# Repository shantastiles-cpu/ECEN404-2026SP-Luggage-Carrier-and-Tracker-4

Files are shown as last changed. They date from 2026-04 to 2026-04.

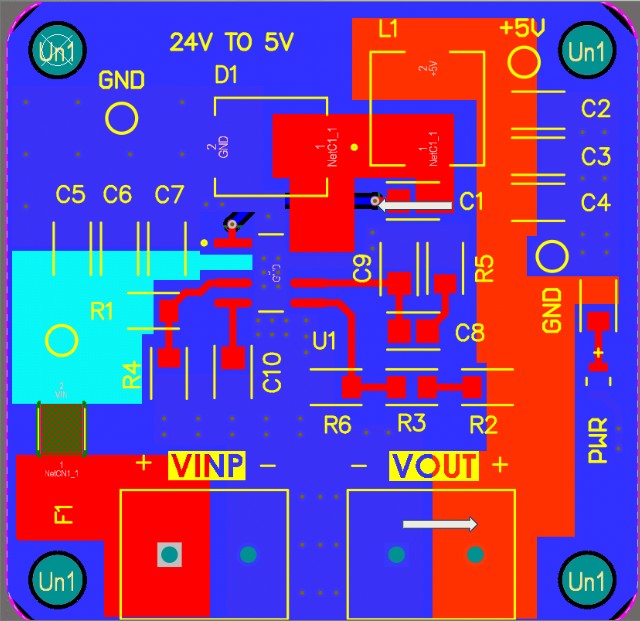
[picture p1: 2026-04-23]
Obstacle Avoidance Subsystem/Buck PCB layout.jpg

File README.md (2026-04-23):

# 🧳 Luggage Carrier and Tracker
ECEN 404 - Senior Design 2025 - 2026

A smart luggage-carrying rover that automatically follows its owner, avoids obstacles, and provides real-time tracking to relieve user fatigue and improve mobility.

## 📌 Project Overview
Problem Statement: Carrying luggage through large areas causes fatigue and logistical issues, particularly for the elderly or disabled.

Solution: An autonomous rover capable of following a designated user while navigating complex environments safely.

## 🛠 Subsystem Breakdown
This project is divided into four major technical subsystems. Detailed documentation and source code for each can be found in their respective directories:

App Subsystem: Flutter-based mobile application for user interface, luggage control, and Supabase integration.

Navigation Subsystem: Core logic for path planning and motor control.

Obstacle Avoidance Subsystem: Sensor integration (Ultrasonic) to ensure safe travel.

Tracking Subsystem: UWB or GPS-based logic for "follow-me" functionality.

## 💻 Tech Stack
Languages: Dart (Flutter) and Python

Cloud/Backend: Supabase (Database & Authentication)

Hardware: Raspberry PI

## 👥 The Team
@shantastiles-cpu

@pgarc04-maker

@aarifnaqvii

@Matt0032

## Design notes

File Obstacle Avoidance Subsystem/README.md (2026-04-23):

## Obstacle Avoidance and Weight Detection Subsystem

This subsystem covers the rover’s obstacle avoidance and weight detection functions.

It includes the ultrasonic sensing hardware and test code, the load cell scale and test code, and the final integrated navigation file where both systems are connected into the full rover operation.

🚀 Getting Started

To use this subsystem, review the included hardware and software files for ultrasonic sensing, load cell testing, and full-system integration.

### 1. Included Files

**four_sensors**
Code used to test the operation of the ultrasonic sensor array. These sensors are powered through a perf board and used to detect obstacles around the rover.

**read_weight**
Code used to test the operation of the load cell luggage scale and output weight readings in the terminal.

**NAVIAPP_MattUpdates4.py**
This is the main integration file where the obstacle avoidance and weight detection systems are combined into the rover’s full navigation and control system.

### 2. Hardware Notes

A large portion of this subsystem involved hardware design and integration.

This includes:

* Ultrasonic sensor array powered through a perf board
* Load cell and HX711 amplifier for luggage weight detection
* Buck converter PCB designed to step 24V down to 5V for Raspberry Pi power

A buck converter PCB was designed and tested for powering the Raspberry Pi from the rover battery system. The board was able to operate at 24V and supply 5A, but because the batteries could produce about 25V, the design was rated slightly too low and the PCB failed under that higher input. The design files and layout have still been included as part of this subsystem.

### 3. Integration

The ultrasonic sensing and weight detection systems are both integrated into the main rover navigation file:

**NAVIAPP_MattUpdates4.py**

This file is located in the home section of the repository and connects these safety systems with the rover’s navigation and control logic.

## Features

Obstacle detection using ultrasonic sensors

Perf board powered sensor array

Load cell luggage weight measurement

Terminal-based weight reading output

Integrated obstacle avoidance logic

Integrated luggage removal safety stop

Buck converter PCB design for Pi power

Combined operation in rover navigation code

Perf board power distribution
Buck converter PCB design

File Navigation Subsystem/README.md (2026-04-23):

# Navigation Subsystem

**Texas A&M University | Electrical & Computer Engineering**

This repository contains the core **Navigation Control Subsystem** for the Luggage Rover 37 capstone project. Operating on a Raspberry Pi 5, this subsystem acts as the brain of the rover's drivetrain. It is fundamentally built around an advanced, mass-adaptive PID controller that translates raw spatial coordinates into smooth, stable motor commands for a differential-drive skid-steer chassis.

## 🚀 System Overview

The Luggage Rover operates with a highly variable payload (0 to 20+ lbs). A statically tuned PID would either respond too sluggishly when fully loaded or violently oscillate when empty. 

To solve this, our navigation core implements **Real-Time Gain Scheduling**. By continuously polling an integrated HX711 load cell, the software dynamically scales the proportional, integral, and derivative coefficients on the fly, ensuring mathematically optimal damping and rise times regardless of the luggage mass.

## ✨ Core PID Architecture

* **Dual-Axis Independent Loops:** The system utilizes two asynchronous PID controllers:
  * **Distance PID:** Governs forward/reverse linear acceleration to maintain a strict 1.0m follow buffer.
  * **Heading PID:** Implements 360-degree wrap-around logic to calculate the shortest rotational path to align the chassis with the user's UWB tag.
* **Real-Time Gain Scheduling:** Actively interpolates `Kp`, `Ki`, and `Kd` parameters based on live payload data, providing necessary inertial load compensation for the heavy Sabertooth-driven drivetrain.
* **Kinematic Slop Compensation:** Injects immediate dynamic power offsets directly to the PID output to break the static friction of heavy rubber tires before the integral loop is forced to "spool up" and cause overshoot.
* **Zero-Effort Deadbands:** Custom 5.0 cm and 5.0° mathematical tolerances immediately cut motor output to absolute zero upon reaching the target zone, eliminating drivetrain micro-jitter and preventing integral windup while resting.
* **Integral Anti-Windup:** Strict mathematical clamping on the integral accumulator prevents runaway oscillation when tracking targets at extended, out-of-bounds ranges.

## 🛠️ Hardware Interface

* **Compute:** Raspberry Pi 5 (Running Python 3)
* **Motor Driver:** Sabertooth 25x2 Dual Motor Controller (Serial at 115200 baud)
* **Telemetry Input:** X/Y tracking coordinates provided by a secondary UWB localization script.

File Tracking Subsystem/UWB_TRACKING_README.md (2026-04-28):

# 📡 UWB Tracking Subsystem

> Real-time 2D user positioning for the Luggage Carrier Rover using Ultra-Wideband ranging, trilateration, and EMA filtering.

---

## Table of Contents

- [Overview](#overview)
- [Hardware](#hardware)
- [Coordinate System](#coordinate-system)
- [Firmware](#firmware)
  - [Anchor Firmware](#anchor-firmware)
  - [Tag Firmware](#tag-firmware)
  - [Antenna Delay Calibration](#antenna-delay-calibration)
- [Software Pipeline](#software-pipeline)
  - [Stage 1 — Port Detection](#stage-1--port-detection)
  - [Stage 2 — Serial Ingestion](#stage-2--serial-ingestion)
  - [Stage 3 — Range Filtering](#stage-3--range-filtering)
  - [Stage 4 — Position Solving](#stage-4--position-solving)
  - [Stage 5 — EMA Smoothing](#stage-5--ema-smoothing)
  - [Stage 6 — Angle and Distance Computation](#stage-6--angle-and-distance-computation)
  - [Stage 7 — Control Distance Rejection](#stage-7--control-distance-rejection)
  - [Stage 8 — Quality Gating](#stage-8--quality-gating)
  - [Stage 9 — Confidence Scoring](#stage-9--confidence-scoring)
- [Configuration](#configuration)
- [Pose Output](#pose-output)
- [Known Limitations](#known-limitations)
- [Dependencies](#dependencies)
- [File Structure](#file-structure)

---

## Overview

The UWB tracking subsystem provides real-time 2D position of a user-carried tag relative to two anchors mounted on the rover. Each anchor independently measures its distance to the tag and reports the result to the Raspberry Pi 5 over USB serial. The Pi solves the tag's position using trilateration and passes distance, heading angle, and confidence to the navigation controller.

---

## Hardware

| Component | Details |
|---|---|
| Anchors | 2× Makerfabs ESP32 UWB (DW1000), USB → Raspberry Pi 5 |
| Tag | 1× Makerfabs ESP32 UWB (DW1000), carried by user |
| Host | Raspberry Pi 5 running `NAVIAPP_MattsUpdates4.py` |
| Anchor separation | 0.65 m (±0.325 m from rover centreline) |
| Ranging mode | `MODE_LONGDATA_RANGE_LOWPOWER` |
| Serial baud rate | 115200 |

---

## Coordinate System

```
             Tag (x, y)
                •
                |
         y      |       ← Y = depth in front of rover
         ↑      |
         |      |
A1 ──────┼──────────── A2      ← anchor wall  (Y = 0)
    (-0.325, 0)  →x  (0.325, 0)
              origin (0, 0)
```

| Axis | Description |
|---|---|
| **X** | Lateral offset from anchor midpoint. Negative = left, positive = right |
| **Y** | Depth in front of the anchor wall. Always positive in normal operation |
| **Distance** | Straight-line distance from rover reference point `(REF_OFFSET_X, REF_OFFSET_Y)` to tag |
| **Angle** | Heading from rover reference point to tag, measured from forward axis. Negative = left, positive = right |

---

## Firmware

### Anchor Firmware

> Files: `anchor1/anchor1.ino`, `anchor2/anchor2.ino`

Each anchor has a unique EUI-64 address and performs DS-TWR (Double-Sided Two-Way Ranging) with the tag. On each completed ranging exchange it streams a JSON frame over USB serial:

```json
{"anchor":"0100","range":1.2340,"dbm":-82.1}
```

On boot it emits an identification message used for auto-detection:

```json
{"event":"boot","anchor":"1"}
```

### Tag Firmware

> File: `tag/tag.ino`

The tag uses the library default antenna delay of `16384` and participates passively in DS-TWR ranging. It does **not** compute positions or transmit data to the Pi — all computation happens on the Pi side.

### Antenna Delay Calibration

The `ANTENNA_DELAY` constant in each anchor compensates for the board's physical hardware propagation delay. To calibrate:

1. Place the tag exactly **1.000 m** from the anchor with clear line of sight
2. Note the reported distance (`measured_m`)
3. Apply the correction formula:

```
new_delay = current_delay + round((measured_m − 1.000) / 0.0046)
```

4. Update `ANTENNA_DELAY` in the anchor firmware and reflash
5. Repeat until the reading is within a few centimetres of 1.000 m

> **Note:** The tag always uses `16384`. Only the anchors are calibrated.  
> **Important:** Calibrate with both anchors mounted on the rover and active simultaneously — the ranging environment affects the result.

Alternatively, flash `anchor_calibrate/anchor_calibrate.ino` which runs a binary search to converge on the correct delay automatically and prints the final value to Serial Monitor.

---

## Software Pipeline

All tracking logic lives in `LocalUwbTracker` inside `NAVIAPP_MattsUpdates4.py`.

```
USB Serial                     Pi Host
───────────────────────────────────────────────────────────────
Anchor 1 ──► AnchorReader 1 ──► bounds check
                                 height compensation           Stage 3
                                 median filter (window=3)
                                        │
Anchor 2 ──► AnchorReader 2 ──►        ▼
             (same filters)    solve_position()                Stage 4
                                 law of cosines → (x, y)
                                        │
                                        ▼
                                 EMA smoothing                 Stage 5
                                 alpha = 0.25
                                        │
                                        ▼
                               angle_deg, distance_m           Stage 6
                               from reference point
                                        │
                                        ▼
                               control drop rejection          Stage 7
                                        │
                                        ▼
                               is_pose_good() gate             Stage 8
                                        │
                                        ▼
                               confidence score                Stage 9
                                        │
                                        ▼
                               → Navigation Controller
```

---

### Stage 1 — Port Detection

At startup, `detect_anchor_ports()` probes USB ports **sequentially** with a 0.5 s gap between each. This avoids a DTR reset race condition where both ESP32s boot simultaneously and interfere with each other's UWB ranging. Each port is toggled via DTR to trigger an ESP32 reset and the boot message is read to confirm anchor presence.

---

### Stage 2 — Serial Ingestion

Two `AnchorReader` threads run in parallel, one per USB port. Each thread reads JSON frames continuously at 115200 baud. The anchor is marked `connected = True` on each valid reading and `connected = False` if no data is received for 3 seconds.

---

### Stage 3 — Range Filtering

Each raw range reading passes three operations in `AnchorReader._parse()`:

#### Bounds Check
```python
if rng < 0.05 or rng > 20.0:
    discard
```

#### Height Compensation

The DW1000 measures 3D slant range. If anchors and tag are at different heights, this is projected to the horizontal floor plane:

$$d_{horizontal} = \sqrt{range^2 - height\_diff^2}$$

where `height_diff = |ANCHOR_HEIGHT_M − TAG_HEIGHT_M|`.

If the slant range is shorter than the height difference (physically impossible noise floor), the reading is clamped to `0.01 m` rather than discarded.

#### Median Filter

A rolling window median filter (`window = 3`) suppresses impulsive multipath noise. Waits for at least 2 samples before outputting.

---

### Stage 4 — Position Solving

The two filtered distances `d1` (A1 → tag) and `d2` (A2 → tag), plus anchor separation `c`, form a triangle. The tag's 2D position is solved using the **law of cosines**:

$$\cos\alpha = \frac{d_1^2 + c^2 - d_2^2}{2 \cdot d_1 \cdot c}$$

$$\sin\alpha = \sqrt{1 - \cos^2\alpha}$$

$$x = d_1 \cdot \cos\alpha - \frac{c}{2}, \quad y = d_1 \cdot \sin\alpha$$

The `c/2` term shifts the origin from A1 to the anchor midpoint. `cos α` is clamped to `[−1, 1]` to absorb small ranging inconsistencies.

---

### Stage 5 — EMA Smoothing

An Exponential Moving Average (`EMA_ALPHA = 0.25`) is applied to raw `x` and `y` before computing angle and distance:

```python
ema_x = 0.25 * raw_x + 0.75 * ema_x
ema_y = 0.25 * raw_y + 0.75 * ema_y
```

Each update blends 25% new reading with 75% history, dampening high-frequency jitter from ranging inconsistencies.

| `EMA_ALPHA` | Behaviour |
|---|---|
| `0.1` | Very smooth, ~700 ms lag |
| `0.25` | Balanced — current setting, ~300–400 ms lag |
| `0.5` | Responsive, some residual jitter |
| `0.8` | Nearly raw output |

---

### Stage 6 — Angle and Distance Computation

From EMA-smoothed `x` and `y`, outputs are computed relative to the **rover reference point** `(REF_OFFSET_X, REF_OFFSET_Y)`:

```python
angle_deg          = atan2(x − REF_OFFSET_X,  y − REF_OFFSET_Y)
distance_control_m = hypot(x − REF_OFFSET_X,  y − REF_OFFSET_Y)
distance_display_m = hypot(x, y)
```

Using the reference point offset ensures `angle = 0°` aligns with the physical forward direction of the rover chassis rather than the anchor wall midpoint.

---

### Stage 7 — Control Distance Rejection

A secondary gate rejects implausible sudden distance drops that could cause an uncontrolled forward charge:

```python
if distance_control_m < MIN_VALID_CONTROL_M:       # 0.50 m
    if last_good − current > MAX_CONTROL_DROP_M:   # 0.35 m
        reject frame, hold last known good value
```

---

### Stage 8 — Quality Gating

Before the pose is passed to the follow controller, all four conditions must pass:

| Condition | Threshold |
|---|---|
| Reading age | < `stale_s` = 1.5 s |
| Anchor 1 connected | `True` |
| Anchor 2 connected | `True` |
| Confidence score | ≥ `min_conf` = 30% |

If any condition fails the rover holds position or transitions to `LOST_UWB` state.

---

### Stage 9 — Confidence Scoring

A 0–100 confidence score is computed from two components:

```
confidence = imbalance_score × 0.6 + distance_score × 0.4
```

- **Imbalance score** — penalises large differences between `d1` and `d2` (tag far off-centre)
- **Distance score** — penalises large Y values (ranging noise has greater angular effect at distance)

---

## Configuration

All tuning constants are defined near the top of `NAVIAPP_MattsUpdates4.py`:

| Constant | Default | Description |
|---|---|---|
| `ANCHOR_HEIGHT_M` | `0.29` | Anchor height above floor (m) |
| `TAG_HEIGHT_M` | `0.89` | Tag height above floor (m) |
| `REF_OFFSET_X` | `0.0` | Reference point X offset from anchor midpoint (m) |
| `REF_OFFSET_Y` | `0.15` | Reference point Y offset — distance in front of anchor wall (m) |
| `MIN_VALID_CONTROL_M` | `0.50` | Minimum believable control distance (m) |
| `MAX_CONTROL_DROP_M` | `0.35` | Maximum believable single-frame distance drop (m) |
| `EMA_ALPHA` | `0.25` | EMA smoothing factor |
| `median_window` | `3` | Median filter window size per anchor |
| `stale_s` | `1.5` | Maximum reading age before pose is stale (s) |
| `min_conf` | `30.0` | Minimum confidence score to act on pose (%) |

---

## Pose Output

`LocalUwbTracker.get()` returns:

```python
{
    "distance_cm":         float,   # control distance from rover reference point (cm)
    "distance_display_cm": float,   # display distance from anchor midpoint (cm)
    "angle_deg":           float,   # heading — negative = left, positive = right
    "confidence":          float,   # quality score 0–100
    "age_s":               float,   # seconds since last valid update
    "a1_connected":        bool,    # anchor 1 connection status
    "a2_connected":        bool,    # anchor 2 connection status
    "a1_age_s":            float,   # seconds since anchor 1 last reading
    "a2_age_s":            float,   # seconds since anchor 2 last reading
    "last_error":          str | None,
}
```

---

## Known Limitations

| Limitation | Detail |
|---|---|
| **Front/behind ambiguity** | With two anchors, `sin α ≥ 0` always — the system cannot distinguish front from behind. Assumes tag is always in front. A BNO055 compass would resolve this. |
| **Near-wall instability** | When tag is very close to anchor wall, small ranging errors produce large angular swings. Avoid operating below ~0.5 m depth. |
| **Multipath reflections** | Median window of 3 suppresses most spikes. Increasing to 5–7 improves rejection at the cost of additional lag. |
| **Antenna delay drift** | Effective delay shifts with temperature and two-anchor operation. Calibrate with both anchors mounted and active on the rover. |

---

## Dependencies

**Python (Pi host):**
```bash
pip3 install pyserial supabase
```

**Arduino (firmware):**
- `DW1000` by Thomas Trojer — install via Arduino Library Manager

---

## File Structure

```
anchor1/
└── anchor1.ino              # Anchor 1 firmware  (EUI-64: 01:00:5B:D5:A9:9A:E2:9C)
anchor2/
└── anchor2.ino              # Anchor 2 firmware  (EUI-64: 02:00:5B:D5:A9:9A:E2:9C)
tag/
└── tag.ino                  # Tag firmware       (antenna delay: 16384)
anchor_calibrate/
└── anchor_calibrate.ino     # Binary search antenna delay calibration sketch
NAVIAPP_MattsUpdates4.py     # Main application — contains LocalUwbTracker
```

---

*Tracking subsystem — Luggage Carrier and Tracker 4 | Team 37 | Texas A&M ECEN 404*

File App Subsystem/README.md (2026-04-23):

# Rover Navigation App

A Flutter-based rover companion app for live navigation, pairing, telemetry monitoring, and validation testing. This app connects to rover data streams, displays positioning and health information, supports manual and autonomous interaction workflows, and exports validation logs for latency and navigation analysis.

## 🚀 Getting Started
To run this app locally, follow these steps:

### 1. Prerequisites
Install the Flutter SDK.

Install Android Studio or VS Code with the Flutter extension.

Ensure you have a physical device or emulator ready.

Create Supabase account to prepare SQL schema

### 2. Installation
Clone the repository:

Bash
git clone https://github.com/shantastiles-cpu/ECEN404-2026SP-Luggage-Carrier-and-Tracker-4.git
Navigate to the App Subsystem directory:

Bash
cd "App Subsystem"
Get the required packages:

Bash
flutter pub get

### 3. Running the App
Launch the app on your connected device using:

Bash
flutter run

### 4. Prepping Database

Copy database_schema.sql commands to the table editor in Supabase

Note: Be sure to enable realtime updates for the tables

## Features

- Rover pairing and reconnection workflow
- Live UWB navigation display
- GPS/map view for rover and user positioning
- Rover telemetry and system health monitoring
- Manual and autonomous mode support
- Realtime Supabase data updates
- Validation testing tools for:
  - UWB and navigation pipeline latency
  - App event logging
  - CSV export for offline analysis
- Visual UI cards for rover state, pairing, and diagnostics

## Tech Stack

- **Flutter**
- **Dart**
- **Supabase**
- **Realtime data subscriptions**
- **CSV export for validation logs**

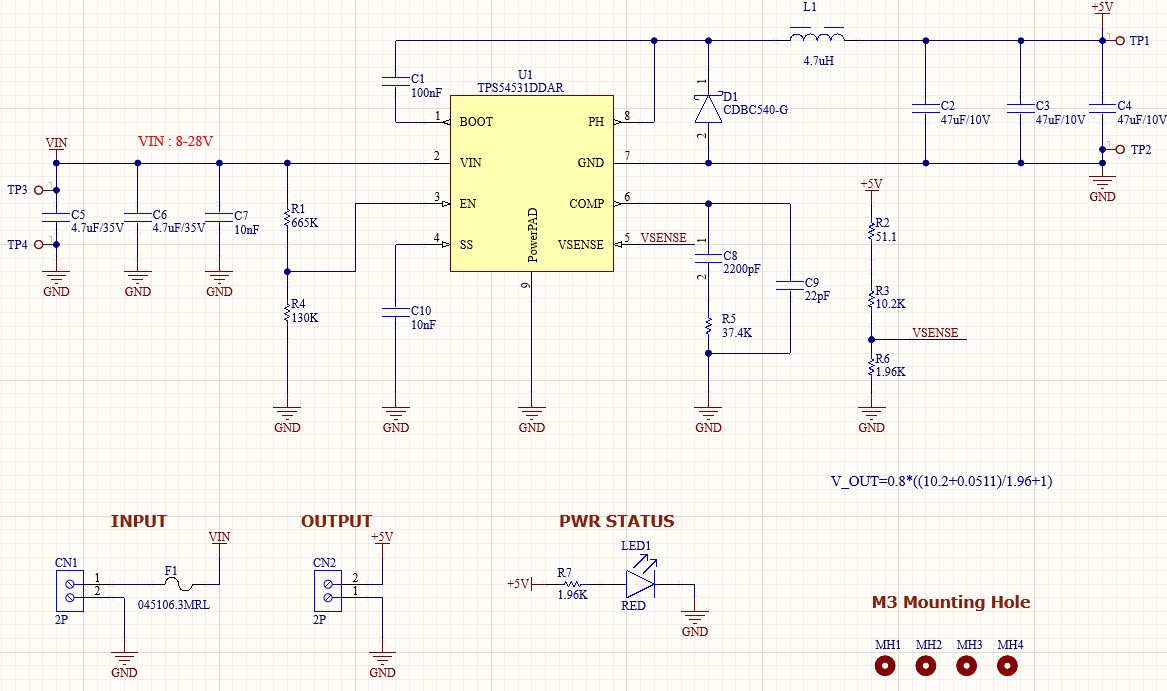
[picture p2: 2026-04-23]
Obstacle Avoidance Subsystem/Buck PCB schematic.jpg

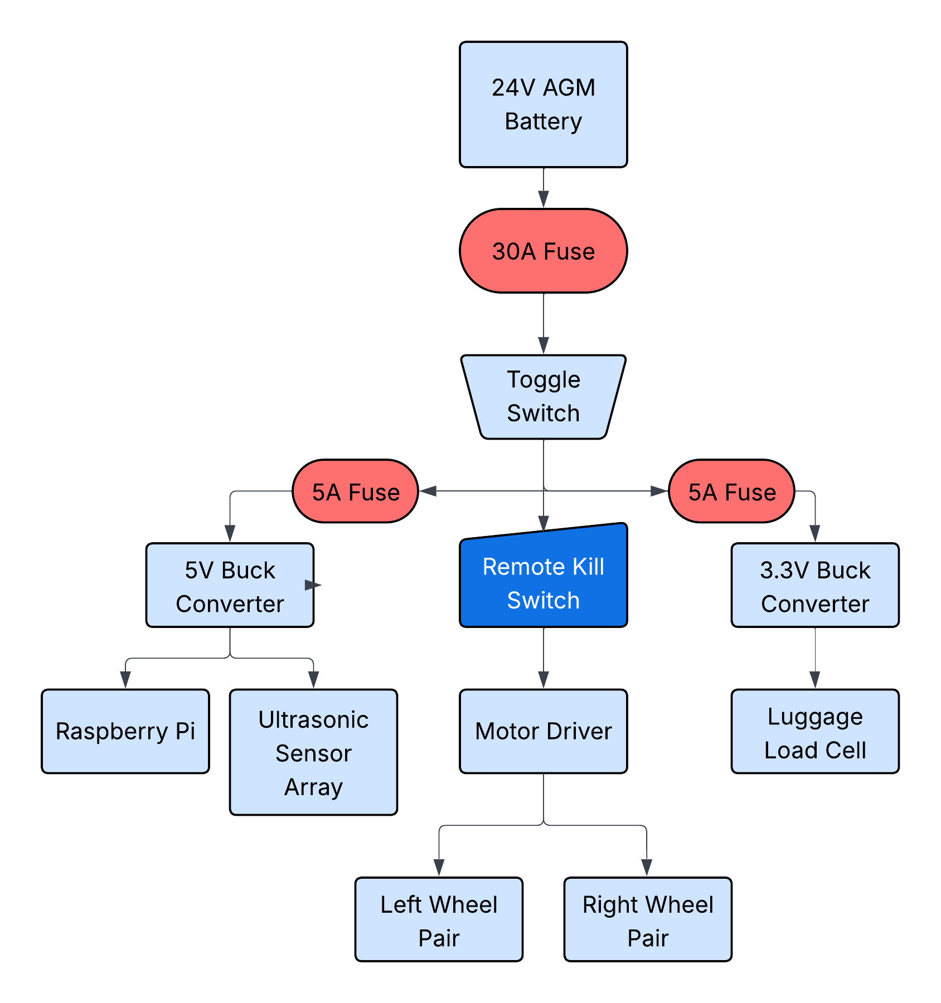
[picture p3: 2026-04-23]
Navigation Subsystem/Power Diagram.png

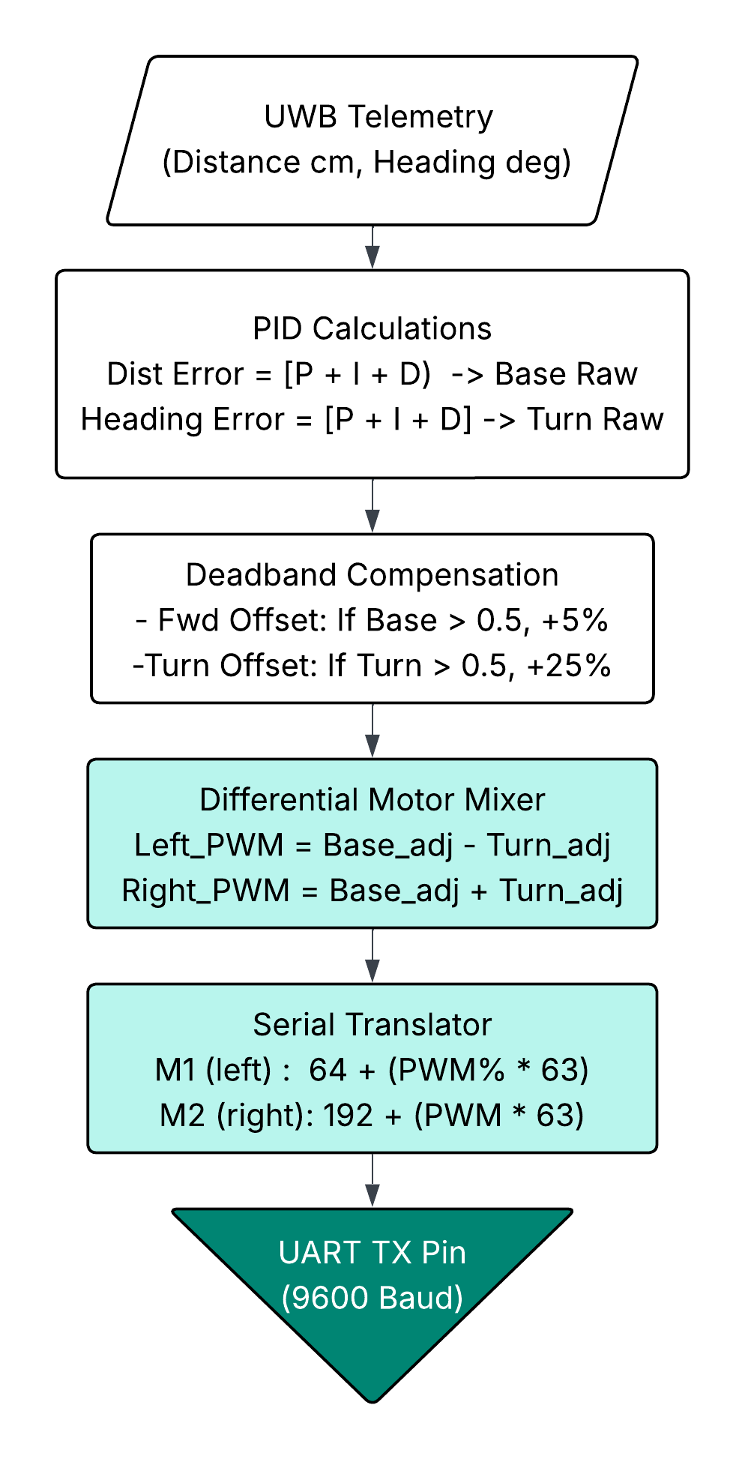
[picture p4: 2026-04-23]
Navigation Subsystem/PID diagram.png

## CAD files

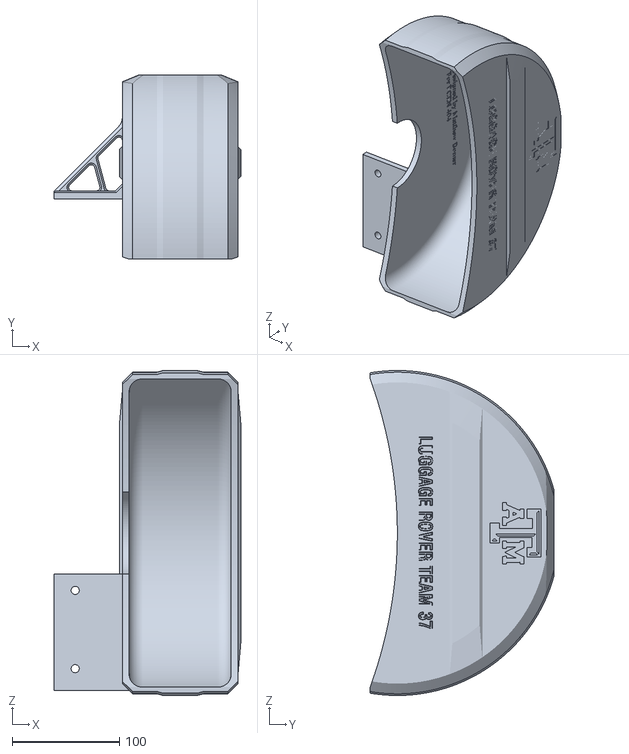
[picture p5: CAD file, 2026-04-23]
Navigation Subsystem/Wheel Arch.stl
174.0 x 171.5 x 303.2

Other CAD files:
Navigation Subsystem/Wheel Arch Mirrored.stl
Navigation Subsystem/Buck Converter Holder.ipt
Navigation Subsystem/Luggage Mount.ipt
Navigation Subsystem/Wheel Arch Mirrored.ipt
Navigation Subsystem/Wheel Arch.ipt

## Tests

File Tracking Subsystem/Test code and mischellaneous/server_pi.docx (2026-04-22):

import json

import numpy as np

import time

import paho.mqtt.client as mqtt

import csv

from datetime import datetime

import os

from collections import deque

# --- CONFIGURATION ---

MQTT_BROKER_IP = "localhost"

MQTT_BROKER_PORT = 1883

DATA_TOPIC = "uwb/tag/data"

STATUS_TOPIC = "uwb/tag/status"

RESULT_TOPIC = "uwb/tag/result"

# --- File Path ---

LOG_FILE_NAME = 'position_log.csv'

# --- 1. CALIBRATION ---

ANCHOR_BIAS = {

"1782": 0.0,

"1783": 0.0,

"1781": 0.0

}

# --- 2. GEOMETRY CONFIG ---

ANCHOR_CONFIG = {

"1782": [-0.204, 0.0],

"1783": [0.204, 0.0],

"1781": [0.0, 0.59]

}

# --- 3. PHYSICS LIMITS ---

MIN_DIST = 0.01

MAX_DIST = 50.0

TAG_HEIGHT = 0.7

MAX_SPEED_MPS = 3.0

ROOM_BOUNDS = { "x_min": -5.0, "x_max": 5.0, "y_min": -5.0, "y_max": 5.0 }

# --- 4. KNOWN START POSITION ---

# We use this to initialize the filter

TRUE_X = 0.0

TRUE_Y = 1.5

# --- 5. SMOOTHING SETTINGS ---

HISTORY_LENGTH = 10

# --- MINI KALMAN FILTER CLASS ---

class MiniKalmanFilter:

def __init__(self):

# --- CALIBRATION CHANGE: Initialize at Known Start ---

# State: [x, y, vx, vy]

# We start at the known position with 0 velocity

self.x = np.array([TRUE_X, TRUE_Y, 0.0, 0.0])

# Initial Uncertainty (P)

# We are very confident about position (low variance),

# but uncertain about velocity (high variance).

self.P = np.diag([0.1, 0.1, 5.0, 5.0])

self.Q = np.eye(4) * 0.0001

self.R = np.eye(2) * (0.3**2)

self.H = np.array([[1, 0, 0, 0], [0, 1, 0, 0]])

self.dt = 0.1

def predict(self):

F = np.array([[1, 0, self.dt, 0], [0, 1, 0, self.dt], [0, 0, 1, 0], [0, 0, 0, 1]])

self.x = np.dot(F, self.x)

self.P = np.dot(np.dot(F, self.P), F.T) + self.Q

def update(self, z):

z = np.array(z)

y = z - np.dot(self.H, self.x)

S = np.dot(np.dot(self.H, self.P), self.H.T) + self.R

K = np.dot(np.dot(self.P, self.H.T), np.linalg.inv(S))

self.x = self.x + np.dot(K, y)

self.P = np.dot((np.eye(4) - np.dot(K, self.H)), self.P)

def trilaterate_2d(anchors, distances):

anchors = np.array(anchors); distances = np.array(distances)

try:

p1 = anchors[0]; r1 = distances[0]

A, b = [], []

for i in range(1, len(anchors)):

pi = anchors[i]; ri = distances[i]

A.append(2 * (pi - p1))

b.append(r1**2 - ri**2 - np.dot(p1, p1) + np.dot(pi, pi))

pos, *_ = np.linalg.lstsq(np.array(A), np.array(b), rcond=None)

return np.array([pos[0], pos[1]])

except: return None

def on_connect(client, userdata, flags, rc):

print(f"Connected to MQTT Broker (Code: {rc})")

client.subscribe(DATA_TOPIC, qos=1)

client.subscribe(STATUS_TOPIC, qos=1)

def is_physically_possible(new_pos, last_pos, dt):

x, y = new_pos

if not (ROOM_BOUNDS["x_min"] <= x <= ROOM_BOUNDS["x_max"]):

print(f" ⚠️ REJECT: Out of bounds ({x:.2f}, {y:.2f})")

return False

if not (ROOM_BOUNDS["y_min"] <= y <= ROOM_BOUNDS["y_max"]):

print(f" ⚠️ REJECT: Out of bounds ({x:.2f}, {y:.2f})")

return False

distance_moved = np.linalg.norm(new_pos - last_pos)

speed = distance_moved / dt

if speed > MAX_SPEED_MPS:

print(f" ⚠️ REJECT: Speed violation ({speed:.2f} m/s)")

return False

return True

def on_message(client, userdata, msg):

if msg.topic == STATUS_TOPIC:

try:

status = msg.payload.decode('utf-8')

print(f"\n== STATUS UPDATE: Tag is now {status} ==\n")

except: pass

return

try:

payload_str = msg.payload.decode('UTF-8')

uwb_data = json.loads(payload_str)

uwb_list = uwb_data.get("links", [])

log_file_handle = client.log_file_handle

log_csv_writer = client.log_csv_writer

kf = client.kalman_filter

history = client.pos_history

current_time = time.time()

last_time = getattr(client, 'last_update_time', current_time - 0.5)

client.last_update_time = current_time

dt = current_time - last_time

kf.dt = dt if dt > 0 else 0.1

except Exception: return

current_anchors, current_distances = [], []

for link in uwb_list:

try:

addr = link.get("A"); raw_dist = float(link.get("R"))

if addr in ANCHOR_CONFIG:

bias = ANCHOR_BIAS.get(addr, 0.0)

d_raw = raw_dist - bias

if d_raw > TAG_HEIGHT:

d_horizontal = np.sqrt(d_raw**2 - TAG_HEIGHT**2)

if MIN_DIST < d_horizontal < MAX_DIST:

current_anchors.append(ANCHOR_CONFIG[addr])

current_distances.append(d_horizontal)

else:

current_anchors.append(ANCHOR_CONFIG[addr])

current_distances.append(0.01)

except Exception: pass

kf.predict()

is_good_measurement = False

tag_est = None

if len(current_anchors) >= 3:

candidate_pos = trilaterate_2d(current_anchors, current_distances)

if candidate_pos is not None:

last_x, last_y = float(kf.x[0]), float(kf.x[1])

if is_physically_possible(candidate_pos, np.array([last_x, last_y]), dt):

is_good_measurement = True

tag_est = candidate_pos

kf.update(z=tag_est)

else:

pass

x_filt_raw = float(kf.x[0])

y_filt_raw = float(kf.x[1])

history.append((x_filt_raw, y_filt_raw))

final_x = sum(p[0] for p in history) / len(history)

final_y = sum(p[1] for p in history) / len(history)

angle_rad = np.arctan2(final_x, final_y)

angle_deg = np.degrees(angle_rad)

dist_origin = np.sqrt(final_x**2 + final_y**2)

error_m = np.sqrt((final_x - TRUE_X)**2 + (final_y - TRUE_Y)**2)

print(f" Pos: ({final_x:.2f}, {final_y:.2f}) | Angle: {angle_deg:.1f}° | Error: {error_m:.2f}m")

try:

result_payload = json.dumps({

"x": final_x, "y": final_y, "angle": angle_deg, "dist": dist_origin, "error": error_m

})

client.publish(RESULT_TOPIC, result_payload)

except: pass

try:

timestamp = datetime.now().isoformat()

calc_x, calc_y = (tag_est[0], tag_est[1]) if is_good_measurement else (np.nan, np.nan)

log_data = [timestamp, calc_x, calc_y, final_x, final_y, angle_deg, dist_origin, TRUE_X, TRUE_Y, error_m]

log_csv_writer.writerow(log_data)

log_file_handle.flush()

except Exception: pass

def main():

print("\n>>> RUNNING SERVER v14 (Calibrated Start) <<<\n")

print(f"Filter Initialized at: ({TRUE_X}, {TRUE_Y})")

file_needs_header = not os.path.exists(LOG_FILE_NAME)

try:

log_file = open(LOG_FILE_NAME, 'a', newline='')

csv_writer = csv.writer(log_file)

if file_needs_header:

csv_writer.writerow(["timestamp", "x_calc", "y_calc", "x_filtered", "y_filtered", "angle_deg", "dist_origin", "x_true", "y_true", "error_m"])

log_file.flush()

except Exception as e: print(f"FATAL: {e}"); return

client = mqtt.Client()

client.kalman_filter = MiniKalmanFilter()

client.pos_history = deque(maxlen=HISTORY_LENGTH)

client.log_file_handle = log_file

client.log_csv_writer = csv_writer

client.last_update_time = time.time()

client.on_connect = on_connect

client.on_message = on_message

try: client.connect(MQTT_BROKER_IP, MQTT_BROKER_PORT, 60)

except Exception as e: print(f"Connection Error: {e}"); log_file.close(); return

client.loop_start()

print("Network loop started. Waiting for UWB data...")

try:

while True: time.sleep(1)

except KeyboardInterrupt:

client.loop_stop(); client.disconnect(); log_file.close()

print("Server stopped.")

if __name__ == '__main__':

main()

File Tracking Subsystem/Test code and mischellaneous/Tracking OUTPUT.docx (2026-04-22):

19:53:29 [INFO] Waiting for readings from both anchors…

19:53:29 [INFO] Waiting for readings from both anchors…

A1= 3.305 m A2= 3.240 m → X= +0.425 m Y= +3.235 m θ= +7.49°

19:53:31 [INFO] HTTP Request: POST https://jbhjvtfeezmityewhtwa.supabase.co/rest/v1/uwb_positions?on_conflict=robot_id "HTTP/2 200 OK"

A1= 3.330 m A2= 3.260 m → X= +0.461 m Y= +3.253 m θ= +8.07°

19:53:31 [INFO] HTTP Request: POST https://jbhjvtfeezmityewhtwa.supabase.co/rest/v1/uwb_positions?on_conflict=robot_id "HTTP/2 200 OK"

A1= 3.340 m A2= 3.270 m → X= +0.463 m Y= +3.263 m θ= +8.07°

19:53:31 [INFO] HTTP Request: POST https://jbhjvtfeezmityewhtwa.supabase.co/rest/v1/uwb_positions?on_conflict=robot_id "HTTP/2 200 OK"

A1= 3.340 m A2= 3.280 m → X= +0.397 m Y= +3.277 m θ= +6.91°

19:53:32 [INFO] HTTP Request: POST https://jbhjvtfeezmityewhtwa.supabase.co/rest/v1/uwb_positions?on_conflict=robot_id "HTTP/2 200 OK"

A1= 3.340 m A2= 3.270 m → X= +0.463 m Y= +3.263 m θ= +8.07°

19:53:32 [INFO] HTTP Request: POST https://jbhjvtfeezmityewhtwa.supabase.co/rest/v1/uwb_positions?on_conflict=robot_id "HTTP/2 200 OK"

A1= 3.300 m A2= 3.280 m → X= +0.132 m Y= +3.278 m θ= +2.30°

19:53:32 [INFO] HTTP Request: POST https://jbhjvtfeezmityewhtwa.supabase.co/rest/v1/uwb_positions?on_conflict=robot_id "HTTP/2 200 OK"

cd /home/matt/Desktop/Tracking

source .venv/bin/activate

python3 SUPA_uwb_host.py

18:54:08 [INFO] Detecting anchors — please wait…

18:54:08 [INFO] Scanning ports: ['/dev/ttyUSB0', '/dev/ttyUSB1']

18:54:10 [INFO] /dev/ttyUSB0 → anchor 2

18:54:10 [INFO] /dev/ttyUSB1 → anchor 1

18:54:14 [INFO] Anchor 1 → /dev/ttyUSB0 pos=(-0.25, 0.00) m

18:54:14 [INFO] Anchor 2 → /dev/ttyUSB1 pos=(0.25, 0.00) m

18:54:14 [INFO] [Anchor 1] Reading from /dev/ttyUSB0

18:54:14 [INFO] [Anchor 2] Reading from /dev/ttyUSB1

18:54:14 [INFO] Positioning started — Ctrl+C to stop

18:54:14 [INFO] Waiting for readings from both anchors…

18:54:14 [INFO] Waiting for readings from both anchors…

18:54:14 [INFO] Waiting for readings from both anchors…

18:54:14 [INFO] Waiting for readings from both anchors…

18:54:15 [INFO] Waiting for readings from both anchors…

18:54:20 [INFO] Waiting for readings from both anchors…

18:54:20 [INFO] Waiting for readings from both anchors…

18:54:20 [INFO] Waiting for readings from both anchors…

18:54:20 [INFO] Waiting for readings from both anchors…

18:54:20 [INFO] [Anchor 2] Event: {'event': 'blink', 'addr': 'A49C'}

18:54:20 [INFO] Waiting for readings from both anchors…

A1= 1.260 m A2= 1.170 m → X= +0.219 m Y= +1.170 m θ= +10.59°

A1= 1.260 m A2= 1.170 m → X= +0.219 m Y= +1.170 m θ= +10.59°

A1= 1.270 m A2= 1.225 m → X= +0.112 m Y= +1.217 m θ= +5.27°

A1= 1.270 m A2= 1.225 m → X= +0.112 m Y= +1.217 m θ= +5.27°

A1= 1.270 m A2= 1.225 m → X= +0.112 m Y= +1.217 m θ= +5.27°

A1= 1.250 m A2= 1.280 m → X= -0.076 m Y= +1.238 m θ= -3.51°

A1= 1.250 m A2= 1.280 m → X= -0.076 m Y= +1.238 m θ= -3.51°

A1= 1.250 m A2= 1.280 m → X= -0.076 m Y= +1.238 m θ= -3.51°

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

A1= 1.250 m A2= 1.305 m → X= -0.141 m Y= +1.245 m θ= -6.44°

A1= 1.250 m A2= 1.305 m → X= -0.141 m Y= +1.245 m θ= -6.44°

A1= 1.250 m A2= 1.305 m → X= -0.141 m Y= +1.245 m θ= -6.44°

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

A1= 1.290 m A2= 1.330 m → X= -0.105 m Y= +1.282 m θ= -4.67°

A1= 1.290 m A2= 1.330 m → X= -0.105 m Y= +1.282 m θ= -4.67°

A1= 1.290 m A2= 1.330 m → X= -0.105 m Y= +1.282 m θ= -4.67°

A1= 1.290 m A2= 1.360 m → X= -0.186 m Y= +1.288 m θ= -8.19°

A1= 1.290 m A2= 1.360 m → X= -0.186 m Y= +1.288 m θ= -8.19°

A1= 1.290 m A2= 1.360 m → X= -0.186 m Y= +1.288 m θ= -8.19°

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

A1= 1.290 m A2= 1.370 m → X= -0.213 m Y= +1.289 m θ= -9.37°

A1= 1.290 m A2= 1.370 m → X= -0.213 m Y= +1.289 m θ= -9.37°

A1= 1.300 m A2= 1.370 m → X= -0.187 m Y= +1.298 m θ= -8.19°

A1= 1.300 m A2= 1.370 m → X= -0.187 m Y= +1.298 m θ= -8.19°

A1= 1.300 m A2= 1.370 m → X= -0.187 m Y= +1.298 m θ= -8.19°

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

A1= 1.360 m A2= 1.340 m → X= +0.054 m Y= +1.326 m θ= +2.33°

A1= 1.360 m A2= 1.340 m → X= +0.054 m Y= +1.326 m θ= +2.33°

A1= 1.360 m A2= 1.340 m → X= +0.054 m Y= +1.326 m θ= +2.33°

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

A1= 1.340 m A2= 1.340 m → X= +0.000 m Y= +1.316 m θ= +0.00°

18:54:28 [WARNING] Stale — A1=0.1s A2=3.0s

18:54:28 [WARNING] Stale — A1=0.1s A2=3.1s

18:54:28 [WARNING] Stale — A1=0.1s A2=3.2s

18:54:28 [WARNING] Stale — A1=0.2s A2=3.3s

18:54:29 [WARNING] Stale — A1=0.3s A2=3.4s

18:54:29 [WARNING] Stale — A1=0.4s A2=3.5s

18:54:29 [WARNING] Stale — A1=0.5s A2=3.6s

18:54:29 [WARNING] Stale — A1=0.6s A2=3.7s

18:54:29 [WARNING] Stale — A1=0.7s A2=3.8s

18:54:29 [WARNING] Stale — A1=0.8s A2=3.9s

18:54:29 [WARNING] Stale — A1=0.1s A2=4.0s

[/dev/ttyUSB1] -> {"anchor":"A49C","range":217.9800,"dbm":-89.5}

[/dev/ttyUSB0] -> {"anchor":"A49C","range":0.5900,"dbm":-83.1}

[/dev/ttyUSB1] -> {"anchor":"A49C","range":-224.7100,"dbm":-89.3}

[/dev/ttyUSB0] -> {"anchor":"A49C","range":0.6800,"dbm":-86.0}

[/dev/ttyUSB1] -> {"anchor":"A49C","range":41.0000,"dbm":-91.2}

[/dev/ttyUSB0] -> {"anchor":"A49C","range":0.5900,"dbm":-86.7}

[/dev/ttyUSB1] -> {"anchor":"A49C","range":254.5300,"dbm":-93.8}

[/dev/ttyUSB0] -> {"anchor":"A49C","range":0.6500,"dbm":-87.9}

[/dev/ttyUSB1] -> {"anchor":"A49C","range":-4.4700,"dbm":-93.6}

[/dev/ttyUSB0] -> {"anchor":"A49C","range":0.6900,"dbm":-87.2}

[/dev/ttyUSB1] -> {"anchor":"A49C","range":8.3500,"dbm":-90.6}

[/dev/ttyUSB0] -> {"anchor":"A49C","range":0.7300,"dbm":-83.7}

[/dev/ttyUSB1] -> {"anchor":"A49C","range":-26.0900,"dbm":-91.6}

[/dev/ttyUSB0] -> {"anchor":"A49C","range":0.8900,"dbm":-85.3}

[/dev/ttyUSB0] -> {"anchor":"A49C","range":1.1900,"dbm":-88.2}

[/dev/ttyUSB0] -> {"anchor":"A49C","range":1.1000,"dbm":-88.3}

[/dev/ttyUSB0] -> {"anchor":"A49C","range":1.2400,"dbm":-90.6}

[/dev/ttyUSB0] -> {"anchor":"A49C","range":1.1500,"dbm":-91.6}

[/dev/ttyUSB0] -> {"anchor":"A49C","range":1.3000,"dbm":-90.5}

[/dev/ttyUSB0] -> {"anchor":"A49C","range":1.3800,"dbm":-91.3}

[/dev/ttyUSB0] -> {"anchor":"A49C","range":1.5400,"dbm":-92.1}

[/dev/ttyUSB0] -> {"anchor":"A49C","range":1.5200,"dbm":-92.2}

[/dev/ttyUSB0] -> {"anchor":"A49C","range":1.5000,"dbm":-92.4}

[/dev/ttyUSB0] -> {"anchor":"A49C","range":1.4500,"dbm":-95.2}

[/dev/ttyUSB0] -> {"anchor":"A49C","range":1.5100,"dbm":-92.7}

[/dev/ttyUSB0] -> {"anchor":"A49C","range":1.5100,"dbm":-96.1}

[/dev/ttyUSB0] -> {"anchor":"A49C","range":1.5200,"dbm":-93.5}

[/dev/ttyUSB1] -> {"event":"inactive","addr":"A49C"}

[/dev/ttyUSB0] -> {"anchor":"A49C","range":1.5000,"dbm":-95.5}

[/dev/ttyUSB0] -> {"anchor":"A49C","range":1.5100,"dbm":-94.7}

[/dev/ttyUSB0] -> {"anchor":"A49C","range":1.5100,"dbm":-93.6}

[/dev/ttyUSB0] -> {"anchor":"A49C","range":1.5200,"dbm":-95.0}

[/dev/ttyUSB0] -> {"anchor":"A49C","range":1.5000,"dbm":-96.6}

[/dev/ttyUSB0] -> {"anchor":"A49C","range":1.5200,"dbm":-93.8}

[/dev/ttyUSB0] -> {"anchor":"A49C","range":1.4800,"dbm":-93.4}

[/dev/ttyUSB0] -> {"anchor":"A49C","range":1.4800,"dbm":-93.4}

[/dev/ttyUSB0] -> {"anchor":"A49C","range":1.5200,"dbm":-93.7}

[/dev/ttyUSB0] -> {"anchor":"A49C","range":1.4300,"dbm":-92.9}

[/dev/ttyUSB0] -> {"anchor":"A49C","range":1.5200,"dbm":-92.8}

[/dev/ttyUSB0] -> {"anchor":"A49C","range":1.4700,"dbm":-93.5}[/dev/ttyUSB0] -> {"anchor":"A49C","range":0.5900,"dbm":-82.3}

17:21:43 [INFO] Detecting anchors — please wait…

17:21:43 [INFO] Scanning ports: ['/dev/ttyUSB0', '/dev/ttyUSB1']

17:21:43 [INFO] Looking for anchors: ['A401', 'A402']

17:21:49 [INFO] /dev/ttyUSB0 → anchor A402

17:21:49 [INFO] /dev/ttyUSB1 → anchor A401

17:21:49 [INFO] Anchor A401 → /dev/ttyUSB1

17:21:49 [INFO] Anchor A402 → /dev/ttyUSB0

17:21:49 [INFO] [Anchor 1 | A401] Reading from /dev/ttyUSB1

17:21:49 [INFO] [Anchor 2 | A402] Reading from /dev/ttyUSB0

17:21:49 [INFO] Positioning started — Ctrl+C to stop

17:21:49 [INFO] Anchor A401 pos=(-0.50, 0.00) m

17:21:49 [INFO] Anchor A402 pos=(0.50, 0.00) m

17:21:49 [INFO] Waiting for readings from both anchors…

17:21:49 [INFO] Waiting for readings from both anchors…

17:21:49 [INFO] Waiting for readings from both anchors…

[/dev/ttyUSB1] -> {"anchor":"A49C","range":1.3700,"dbm":-73.4}

[/dev/ttyUSB0] -> {"anchor":"A49C","range":1.7300,"dbm":-84.2}

[/dev/ttyUSB1] -> {"anchor":"A49C","range":1.3700,"dbm":-77.8}

[/dev/ttyUSB0] -> {"anchor":"A49C","range":1.7100,"dbm":-89.3}

[/dev/ttyUSB1] -> {"anchor":"A49C","range":1.7100,"dbm":-68.6}

[/dev/ttyUSB0] -> {"anchor":"A49C","range":1.6300,"dbm":-84.3}

[/dev/ttyUSB1] -> {"anchor":"A49C","range":1.4300,"dbm":-66.7}

[/dev/ttyUSB0] -> {"anchor":"A49C","range":1.6200,"dbm":-77.9}

[/dev/ttyUSB1] -> {"anchor":"A49C","range":1.8400,"dbm":-93.7}

[/dev/ttyUSB1] -> {"anchor":"A49C","range":1.3300,"dbm":-66.8}

[/dev/ttyUSB1] -> Rebooting...

[/dev/ttyUSB0] -> A14 : 0x00000000 A15 : 0x0000cdcd SAR : 0x0000001c EXCCAUSE: 0x00000006

[/dev/ttyUSB1] -> ets Jul 29 2019 12:21:46

[/dev/ttyUSB0] -> EXCVADDR: 0x00000000 LBEG : 0x00000000 LEND : 0x00000000 LCOUNT : 0x00000000

[/dev/ttyUSB1] -> rst:0xc (SW_CPU_RESET),boot:0x13 (SPI_FAST_FLASH_BOOT)

[/dev/ttyUSB1] -> configsip: 0, SPIWP:0xee

[/dev/ttyUSB0] -> Backtrace: 0x40085706:0x3ffbf30c |<-CORRUPTED

[/dev/ttyUSB1] -> clk_drv:0x00,q_drv:0x00,d_drv:0x00,cs0_drv:0x00,hd_drv:0x00,wp_drv:0x00

[/dev/ttyUSB1] -> mode:DIO, clock div:1

[/dev/ttyUSB1] -> load:0x3fff0030,len:4980

[/dev/ttyUSB1] -> load:0x40078000,len:16612

[/dev/ttyUSB1] -> load:0x40080400,len:3500

[/dev/ttyUSB0] -> ELF file SHA256: 5cd2ae720

[/dev/ttyUSB1] -> entry 0x400805b4

[/dev/ttyUSB0] -> Rebooting...

[/dev/ttyUSB0] -> ets Jul 29 2019 12:21:46

[/dev/ttyUSB0] -> rst:0xc (SW_CPU_RESET),boot:0x13 (SPI_FAST_FLASH_BOOT)

[/dev/ttyUSB0] -> configsip: 0, SPIWP:0xee

[/dev/ttyUSB0] -> clk_drv:0x00,q_drv:0x00,d_drv:0x00,cs0_drv:0x00,hd_drv:0x00,wp_drv:0x00

[/dev/ttyUSB0] -> mode:DIO, clock div:1

[/dev/ttyUSB0] -> load:0x3fff0030,len:4980

[/dev/ttyUSB0] -> load:0x40078000,len:16612

[/dev/ttyUSB0] -> load:0x40080400,len:3500

[/dev/ttyUSB0] -> entry 0x400805b4

[/dev/ttyUSB1] -> Guru Meditation Error: Core 1 panic'ed (Interrupt wdt timeout on CPU1).

[/dev/ttyUSB1] -> Core 1 register dump:

[/dev/ttyUSB1] -> PC : 0x40088e1f PS : 0x00060035 A0 : 0x8008993c A1 : 0x3ffbfa3c

[/dev/ttyUSB1] -> A2 : 0x3ffb7c60 A3 : 0x3ffb81a0 A4 : 0xb33fffff A5 : 0x00060023

[/dev/ttyUSB1] -> A6 : 0x3ffc28dc A7 : 0x0000abab A8 : 0x3ffb81a0 A9 : 0x00000018

[/dev/ttyUSB1] -> A10 : 0x00000018 A11 : 0x0000008e A12 : 0xb33fffff A13 : 0x3f40babc

[/dev/ttyUSB1] -> A14 : 0x00000003 A15 : 0x0000abab SAR : 0x0000001e EXCCAUSE: 0x00000006

[/dev/ttyUSB1] -> EXCVADDR: 0x00000000 LBEG : 0x40083145 LEND : 0x4008314d LCOUNT : 0x00000027

[/dev/ttyUSB1] -> Core 1 was running in ISR context:

[/dev/ttyUSB1] -> EPC1 : 0x400dc863 EPC2 : 0x00000000 EPC3 : 0x00000000 EPC4 : 0x00000000

[/dev/ttyUSB0] -> Guru Meditation Error: Core 1 panic'ed (Interrupt wdt timeout on CPU1).

[/dev/ttyUSB1] -> Backtrace: 0x40088e1c:0x3ffbfa3c |<-CORRUPTED

[/dev/ttyUSB0] -> Core 1 register dump:

[/dev/ttyUSB0] -> PC : 0x40088e1f PS : 0x00060035 A0 : 0x8008993c A1 : 0x3ffbfa3c

[/dev/ttyUSB0] -> A2 : 0x3ffb7c60 A3 : 0x3ffb81a0 A4 : 0xb33fffff A5 : 0x00060023

[/dev/ttyUSB1] -> Core 0 register dump:

[/dev/ttyUSB0] -> A6 : 0x3ffc28dc A7 : 0x0000abab A8 : 0x3ffb81a0 A9 : 0x00000018

[/dev/ttyUSB1] -> PC : 0x40085709 PS : 0x00060035 A0 : 0x800884e4 A1 : 0x3ffbf30c

[/dev/ttyUSB0] -> A10 : 0x00000018 A11 : 0x0000008e A12 : 0xb33fffff A13 : 0x3f40babc

[/dev/ttyUSB1] -> A2 : 0x00000000 A3 : 0xb33f5454 A4 : 0x0000abab A5 : 0x3f40ba38

[/dev/ttyUSB0] -> A14 : 0x00000003 A15 : 0x0000abab SAR : 0x0000001e EXCCAUSE: 0x00000006

[/dev/ttyUSB1] -> A6 : 0x3ffbc30c A7 : 0x3ffb656c A8 : 0x007bddb0 A9 : 0x3ffbddb0

[/dev/ttyUSB0] -> EXCVADDR: 0x00000000 LBEG : 0x40083145 LEND : 0x4008314d LCOUNT : 0x00000027

[/dev/ttyUSB1] -> A10 : 0x003fffff A11 : 0x00000000 A12 : 0x80088591 A13 : 0x3ffc3800

[/dev/ttyUSB0] -> Core 1 was running in ISR context:

[/dev/ttyUSB1] -> A14 : 0x00000003 A15 : 0x00060023 SAR : 0x0000001c EXCCAUSE: 0x00000006

[/dev/ttyUSB0] -> EPC1 : 0x400dc863 EPC2 : 0x00000000 EPC3 : 0x00000000 EPC4 : 0x00000000

[/dev/ttyUSB1] -> EXCVADDR: 0x00000000 LBEG : 0x00000000 LEND : 0x00000000 LCOUNT : 0x00000000

[/dev/ttyUSB0] -> Backtrace: 0x40088e1c:0x3ffbfa3c |<-CORRUPTED

00:53:36 [INFO] Waiting for readings from both anchors…

00:53:36 [INFO] [Anchor 1] Event: {'event': 'boot', 'anchor': 1}

00:53:37 [INFO] Waiting for readings from both anchors…

00:53:37 [INFO] Waiting for readings from both anchors…

00:53:37 [INFO] [Anchor 2] Event: {'event': 'boot', 'anchor': 2}

00:53:37 [INFO] Waiting for readings from both anchors…

00:53:37 [INFO] Waiting for readings from both anchors…

00:53:37 [INFO] Waiting for readings from both anchors…

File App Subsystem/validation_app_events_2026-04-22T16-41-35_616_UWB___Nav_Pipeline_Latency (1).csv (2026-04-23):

ts_iso | session_id | test_name | event_type | paired | pipeline_latency_ms | Average Latency = 163.27051
2026-04-22T21:41:59.448Z | 2026-04-22T16-41-35.616_UWB_&_Nav_Pipeline_Latency | UWB & Nav Pipeline Latency | uwb_update | TRUE | 664
2026-04-22T21:41:42.123Z | 2026-04-22T16-41-35.616_UWB_&_Nav_Pipeline_Latency | UWB & Nav Pipeline Latency | rover_live_state_update | TRUE | 629
2026-04-22T21:41:36.219Z | 2026-04-22T16-41-35.616_UWB_&_Nav_Pipeline_Latency | UWB & Nav Pipeline Latency | uwb_update | TRUE | 542
2026-04-22T21:41:59.449Z | 2026-04-22T16-41-35.616_UWB_&_Nav_Pipeline_Latency | UWB & Nav Pipeline Latency | uwb_update | TRUE | 506
2026-04-22T21:41:41.389Z | 2026-04-22T16-41-35.616_UWB_&_Nav_Pipeline_Latency | UWB & Nav Pipeline Latency | rover_live_state_update | TRUE | 468
2026-04-22T21:41:38.099Z | 2026-04-22T16-41-35.616_UWB_&_Nav_Pipeline_Latency | UWB & Nav Pipeline Latency | uwb_update | TRUE | 387
2026-04-22T21:41:42.141Z | 2026-04-22T16-41-35.616_UWB_&_Nav_Pipeline_Latency | UWB & Nav Pipeline Latency | uwb_update | TRUE | 386
2026-04-22T21:42:25.156Z | 2026-04-22T16-41-35.616_UWB_&_Nav_Pipeline_Latency | UWB & Nav Pipeline Latency | rover_live_state_update | TRUE | 386
2026-04-22T21:43:01.863Z | 2026-04-22T16-41-35.616_UWB_&_Nav_Pipeline_Latency | UWB & Nav Pipeline Latency | uwb_update | TRUE | 386
2026-04-22T21:41:37.523Z | 2026-04-22T16-41-35.616_UWB_&_Nav_Pipeline_Latency | UWB & Nav Pipeline Latency | rover_live_state_update | TRUE | 385
2026-04-22T21:42:15.307Z | 2026-04-22T16-41-35.616_UWB_&_Nav_Pipeline_Latency | UWB & Nav Pipeline Latency | uwb_update | TRUE | 372
2026-04-22T21:42:45.371Z | 2026-04-22T16-41-35.616_UWB_&_Nav_Pipeline_Latency | UWB & Nav Pipeline Latency | uwb_update | TRUE | 372
2026-04-22T21:41:49.607Z | 2026-04-22T16-41-35.616_UWB_&_Nav_Pipeline_Latency | UWB & Nav Pipeline Latency | rover_live_state_update | TRUE | 363
2026-04-22T21:42:15.852Z | 2026-04-22T16-41-35.616_UWB_&_Nav_Pipeline_Latency | UWB & Nav Pipeline Latency | telemetry_snapshots_update | TRUE | 363
2026-04-22T21:42:46.004Z | 2026-04-22T16-41-35.616_UWB_&_Nav_Pipeline_Latency | UWB & Nav Pipeline Latency | uwb_update | TRUE | 363
2026-04-22T21:41:57.202Z | 2026-04-22T16-41-35.616_UWB_&_Nav_Pipeline_Latency | UWB & Nav Pipeline Latency | uwb_update | TRUE | 354
2026-04-22T21:41:44.455Z | 2026-04-22T16-41-35.616_UWB_&_Nav_Pipeline_Latency | UWB & Nav Pipeline Latency | uwb_update | TRUE | 353
2026-04-22T21:42:07.670Z | 2026-04-22T16-41-35.616_UWB_&_Nav_Pipeline_Latency | UWB & Nav Pipeline Latency | uwb_update | TRUE | 353
2026-04-22T21:42:31.576Z | 2026-04-22T16-41-35.616_UWB_&_Nav_Pipeline_Latency | UWB & Nav Pipeline Latency | uwb_update | TRUE | 353
2026-04-22T21:41:59.450Z | 2026-04-22T16-41-35.616_UWB_&_Nav_Pipeline_Latency | UWB & Nav Pipeline Latency | rover_live_state_update | TRUE | 349
2026-04-22T21:42:09.789Z | 2026-04-22T16-41-35.616_UWB_&_Nav_Pipeline_Latency | UWB & Nav Pipeline Latency | uwb_update | TRUE | 349
2026-04-22T21:42:09.803Z | 2026-04-22T16-41-35.616_UWB_&_Nav_Pipeline_Latency | UWB & Nav Pipeline Latency | uwb_update | TRUE | 349
2026-04-22T21:41:36.222Z | 2026-04-22T16-41-35.616_UWB_&_Nav_Pipeline_Latency | UWB & Nav Pipeline Latency | rover_live_state_update | TRUE | 346
2026-04-22T21:42:22.392Z | 2026-04-22T16-41-35.616_UWB_&_Nav_Pipeline_Latency | UWB & Nav Pipeline Latency | uwb_update | TRUE | 346
2026-04-22T21:42:05.504Z | 2026-04-22T16-41-35.616_UWB_&_Nav_Pipeline_Latency | UWB & Nav Pipeline Latency | rover_live_state_update | TRUE | 340
2026-04-22T21:42:28.322Z | 2026-04-22T16-41-35.616_UWB_&_Nav_Pipeline_Latency | UWB & Nav Pipeline Latency | uwb_update | TRUE | 340
2026-04-22T21:42:23.660Z | 2026-04-22T16-41-35.616_UWB_&_Nav_Pipeline_Latency | UWB & Nav Pipeline Latency | uwb_update | TRUE | 339
2026-04-22T21:42:59.340Z | 2026-04-22T16-41-35.616_UWB_&_Nav_Pipeline_Latency | UWB & Nav Pipeline Latency | uwb_update | TRUE | 339
2026-04-22T21:42:10.141Z | 2026-04-22T16-41-35.616_UWB_&_Nav_Pipeline_Latency | UWB & Nav Pipeline Latency | telemetry_snapshots_update | TRUE | 335
2026-04-22T21:42:23.653Z | 2026-04-22T16-41-35.616_UWB_&_Nav_Pipeline_Latency | UWB & Nav Pipeline Latency | rover_live_state_update | TRUE | 329
2026-04-22T21:41:46.624Z | 2026-04-22T16-41-35.616_UWB_&_Nav_Pipeline_Latency | UWB & Nav Pipeline Latency | rover_live_state_update | TRUE | 328
2026-04-22T21:42:06.988Z | 2026-04-22T16-41-35.616_UWB_&_Nav_Pipeline_Latency | UWB & Nav Pipeline Latency | uwb_update | TRUE | 328
2026-04-22T21:42:30.875Z | 2026-04-22T16-41-35.616_UWB_&_Nav_Pipeline_Latency | UWB & Nav Pipeline Latency | uwb_update | TRUE | 328
2026-04-22T21:42:04.691Z | 2026-04-22T16-41-35.616_UWB_&_Nav_Pipeline_Latency | UWB & Nav Pipeline Latency | rover_live_state_update | TRUE | 325
2026-04-22T21:41:51.023Z | 2026-04-22T16-41-35.616_UWB_&_Nav_Pipeline_Latency | UWB & Nav Pipeline Latency | rover_live_state_update | TRUE | 324
2026-04-22T21:42:08.501Z | 2026-04-22T16-41-35.616_UWB_&_Nav_Pipeline_Latency | UWB & Nav Pipeline Latency | uwb_update | TRUE | 324
2026-04-22T21:42:14.438Z | 2026-04-22T16-41-35.616_UWB_&_Nav_Pipeline_Latency | UWB & Nav Pipeline Latency | uwb_update | TRUE | 321
2026-04-22T21:42:43.852Z | 2026-04-22T16-41-35.616_UWB_&_Nav_Pipeline_Latency | UWB & Nav Pipeline Latency | uwb_update | TRUE | 321
2026-04-22T21:42:10.443Z | 2026-04-22T16-41-35.616_UWB_&_Nav_Pipeline_Latency | UWB & Nav Pipeline Latency | uwb_update | TRUE | 318
2026-04-22T21:41:41.574Z | 2026-04-22T16-41-35.616_UWB_&_Nav_Pipeline_Latency | UWB & Nav Pipeline Latency | uwb_update | TRUE | 317
2026-04-22T21:42:03.057Z | 2026-04-22T16-41-35.616_UWB_&_Nav_Pipeline_Latency | UWB & Nav Pipeline Latency | uwb_update | TRUE | 315
2026-04-22T21:42:21.616Z | 2026-04-22T16-41-35.616_UWB_&_Nav_Pipeline_Latency | UWB & Nav Pipeline Latency | uwb_update | TRUE | 314
2026-04-22T21:42:55.845Z | 2026-04-22T16-41-35.616_UWB_&_Nav_Pipeline_Latency | UWB & Nav Pipeline Latency | uwb_update | TRUE | 314
2026-04-22T21:41:36.223Z | 2026-04-22T16-41-35.616_UWB_&_Nav_Pipeline_Latency | UWB & Nav Pipeline Latency | uwb_update | TRUE | 307
2026-04-22T21:41:41.370Z | 2026-04-22T16-41-35.616_UWB_&_Nav_Pipeline_Latency | UWB & Nav Pipeline Latency | uwb_update | TRUE | 306
2026-04-22T21:41:36.231Z | 2026-04-22T16-41-35.616_UWB_&_Nav_Pipeline_Latency | UWB & Nav Pipeline Latency | rover_live_state_update | TRUE | 302
2026-04-22T21:42:06.978Z | 2026-04-22T16-41-35.616_UWB_&_Nav_Pipeline_Latency | UWB & Nav Pipeline Latency | telemetry_snapshots_update | TRUE | 298
2026-04-22T21:42:30.138Z | 2026-04-22T16-41-35.616_UWB_&_Nav_Pipeline_Latency | UWB & Nav Pipeline Latency | uwb_update | TRUE | 298
2026-04-22T21:42:18.288Z | 2026-04-22T16-41-35.616_UWB_&_Nav_Pipeline_Latency | UWB & Nav Pipeline Latency | uwb_update | TRUE | 296
2026-04-22T21:41:37.521Z | 2026-04-22T16-41-35.616_UWB_&_Nav_Pipeline_Latency | UWB & Nav Pipeline Latency | uwb_update | TRUE | 293
2026-04-22T21:42:13.105Z | 2026-04-22T16-41-35.616_UWB_&_Nav_Pipeline_Latency | UWB & Nav Pipeline Latency | uwb_update | TRUE | 293
2026-04-22T21:41:40.086Z | 2026-04-22T16-41-35.616_UWB_&_Nav_Pipeline_Latency | UWB & Nav Pipeline Latency | uwb_update | TRUE | 290
2026-04-22T21:42:11.066Z | 2026-04-22T16-41-35.616_UWB_&_Nav_Pipeline_Latency | UWB & Nav Pipeline Latency | rover_live_state_update | TRUE | 289
2026-04-22T21:42:09.162Z | 2026-04-22T16-41-35.616_UWB_&_Nav_Pipeline_Latency | UWB & Nav Pipeline Latency | uwb_update | TRUE | 288
2026-04-22T21:42:22.921Z | 2026-04-22T16-41-35.616_UWB_&_Nav_Pipeline_Latency | UWB & Nav Pipeline Latency | rover_live_state_update | TRUE | 287
2026-04-22T21:42:57.846Z | 2026-04-22T16-41-35.616_UWB_&_Nav_Pipeline_Latency | UWB & Nav Pipeline Latency | uwb_update | TRUE | 287
2026-04-22T21:42:23.651Z | 2026-04-22T16-41-35.616_UWB_&_Nav_Pipeline_Latency | UWB & Nav Pipeline Latency | uwb_update | TRUE | 286
2026-04-22T21:41:44.966Z | 2026-04-22T16-41-35.616_UWB_&_Nav_Pipeline_Latency | UWB & Nav Pipeline Latency | rover_live_state_update | TRUE | 285
2026-04-22T21:41:53.170Z | 2026-04-22T16-41-35.616_UWB_&_Nav_Pipeline_Latency | UWB & Nav Pipeline Latency | uwb_update | TRUE | 285
2026-04-22T21:41:53.169Z | 2026-04-22T16-41-35.616_UWB_&_Nav_Pipeline_Latency | UWB & Nav Pipeline Latency | uwb_update | TRUE | 283
2026-04-22T21:42:02.147Z | 2026-04-22T16-41-35.616_UWB_&_Nav_Pipeline_Latency | UWB & Nav Pipeline Latency | telemetry_snapshots_update | TRUE | 282
2026-04-22T21:41:47.895Z | 2026-04-22T16-41-35.616_UWB_&_Nav_Pipeline_Latency | UWB & Nav Pipeline Latency | rover_live_state_update | TRUE | 281
2026-04-22T21:41:52.571Z | 2026-04-22T16-41-35.616_UWB_&_Nav_Pipeline_Latency | UWB & Nav Pipeline Latency | uwb_update | TRUE | 281
2026-04-22T21:42:03.863Z | 2026-04-22T16-41-35.616_UWB_&_Nav_Pipeline_Latency | UWB & Nav Pipeline Latency | rover_live_state_update | TRUE | 281
2026-04-22T21:41:53.851Z | 2026-04-22T16-41-35.616_UWB_&_Nav_Pipeline_Latency | UWB & Nav Pipeline Latency | uwb_update | TRUE | 280
2026-04-22T21:42:03.049Z | 2026-04-22T16-41-35.616_UWB_&_Nav_Pipeline_Latency | UWB & Nav Pipeline Latency | uwb_update | TRUE | 279
2026-04-22T21:42:12.351Z | 2026-04-22T16-41-35.616_UWB_&_Nav_Pipeline_Latency | UWB & Nav Pipeline Latency | uwb_update | TRUE | 279
2026-04-22T21:42:40.335Z | 2026-04-22T16-41-35.616_UWB_&_Nav_Pipeline_Latency | UWB & Nav Pipeline Latency | uwb_update | TRUE | 279
2026-04-22T21:42:14.579Z | 2026-04-22T16-41-35.616_UWB_&_Nav_Pipeline_Latency | UWB & Nav Pipeline Latency | uwb_update | TRUE | 278
2026-04-22T21:41:58.626Z | 2026-04-22T16-41-35.616_UWB_&_Nav_Pipeline_Latency | UWB & Nav Pipeline Latency | uwb_update | TRUE | 275
2026-04-22T21:42:00.290Z | 2026-04-22T16-41-35.616_UWB_&_Nav_Pipeline_Latency | UWB & Nav Pipeline Latency | rover_live_state_update | TRUE | 275
2026-04-22T21:42:01.632Z | 2026-04-22T16-41-35.616_UWB_&_Nav_Pipeline_Latency | UWB & Nav Pipeline Latency | rover_live_state_update | TRUE | 275
2026-04-22T21:42:18.286Z | 2026-04-22T16-41-35.616_UWB_&_Nav_Pipeline_Latency | UWB & Nav Pipeline Latency | rover_live_state_update | TRUE | 275
2026-04-22T21:41:59.809Z | 2026-04-22T16-41-35.616_UWB_&_Nav_Pipeline_Latency | UWB & Nav Pipeline Latency | telemetry_snapshots_update | TRUE | 274
2026-04-22T21:41:42.145Z | 2026-04-22T16-41-35.616_UWB_&_Nav_Pipeline_Latency | UWB & Nav Pipeline Latency | uwb_update | TRUE | 273
2026-04-22T21:41:55.347Z | 2026-04-22T16-41-35.616_UWB_&_Nav_Pipeline_Latency | UWB & Nav Pipeline Latency | rover_live_state_update | TRUE | 273
2026-04-22T21:41:58.635Z | 2026-04-22T16-41-35.616_UWB_&_Nav_Pipeline_Latency | UWB & Nav Pipeline Latency | rover_live_state_update | TRUE | 273
2026-04-22T21:42:04.858Z | 2026-04-22T16-41-35.616_UWB_&_Nav_Pipeline_Latency | UWB & Nav Pipeline Latency | uwb_update | TRUE | 273
2026-04-22T21:42:13.645Z | 2026-04-22T16-41-35.616_UWB_&_Nav_Pipeline_Latency | UWB & Nav Pipeline Latency | uwb_update | TRUE | 272
2026-04-22T21:42:01.101Z | 2026-04-22T16-41-35.616_UWB_&_Nav_Pipeline_Latency | UWB & Nav Pipeline Latency | uwb_update | TRUE | 271
2026-04-22T21:42:20.952Z | 2026-04-22T16-41-35.616_UWB_&_Nav_Pipeline_Latency | UWB & Nav Pipeline Latency | rover_live_state_update | TRUE | 271
2026-04-22T21:42:55.076Z | 2026-04-22T16-41-35.616_UWB_&_Nav_Pipeline_Latency | UWB & Nav Pipeline Latency | uwb_update | TRUE | 271
2026-04-22T21:41:52.558Z | 2026-04-22T16-41-35.616_UWB_&_Nav_Pipeline_Latency | UWB & Nav Pipeline Latency | uwb_update | TRUE | 267
2026-04-22T21:41:58.994Z | 2026-04-22T16-41-35.616_UWB_&_Nav_Pipeline_Latency | UWB & Nav Pipeline Latency | telemetry_snapshots_update | TRUE | 267
2026-04-22T21:42:13.115Z | 2026-04-22T16-41-35.616_UWB_&_Nav_Pipeline_Latency | UWB & Nav Pipeline Latency | uwb_update | TRUE | 267
2026-04-22T21:41:40.768Z | 2026-04-22T16-41-35.616_UWB_&_Nav_Pipeline_Latency | UWB & Nav Pipeline Latency | uwb_update | TRUE | 264
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

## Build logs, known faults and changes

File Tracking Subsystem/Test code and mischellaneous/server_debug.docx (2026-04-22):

import json

import numpy as np

import time

import paho.mqtt.client as mqtt

import os

# --- CONFIGURATION ---

MQTT_BROKER_IP = "localhost"

MQTT_BROKER_PORT = 1883

DATA_TOPIC = "uwb/tag/data"

# --- ANCHOR CONFIG (Verify these!) ---

ANCHOR_CONFIG = {

"1782": [-0.204, 0.0],

"1783": [0.204, 0.0],

"1781": [0.0, 0.59]

}

ANCHOR_BIAS = { "1782": 0.0, "1783": 0.0, "1781": 0.0 }

MIN_DIST = 0.01

MAX_DIST = 50.0

TAG_HEIGHT = 0.7

def on_connect(client, userdata, flags, rc):

print(f"✅ DEBUG SERVER CONNECTED (Code: {rc})")

client.subscribe(DATA_TOPIC)

def on_message(client, userdata, msg):

try:

payload_str = msg.payload.decode('UTF-8')

print(f"\n📦 RAW PACKET: {payload_str}") # PRINT RAW DATA

uwb_data = json.loads(payload_str)

links = uwb_data.get("links", [])

valid_anchors = 0

for link in links:

addr = link.get("A")

raw_dist = float(link.get("R"))

# Check 1: ID Match

if addr not in ANCHOR_CONFIG:

print(f" ❌ UNKNOWN ID: {addr} (Not in config)")

continue

# Check 2: Distance Range

bias = ANCHOR_BIAS.get(addr, 0.0)

d_raw = raw_dist - bias

if d_raw <= TAG_HEIGHT:

print(f" ⚠️ LOW DISTANCE: {d_raw:.2f}m <= Height {TAG_HEIGHT}m (Tag under anchor?)")

# We accept this but treat it as 0 horizontal

if d_raw > MAX_DIST:

print(f" ❌ DISTANCE TOO FAR: {d_raw:.2f}m")

continue

print(f" ✅ VALID LINK: Anchor {addr} -> Dist {d_raw:.2f}m")

valid_anchors += 1

if valid_anchors < 3:

print(f" ⚠️ MATH REJECT: Only {valid_anchors} valid links (Need 3)")

else:

print(f" 🎯 MATH READY: Have {valid_anchors} anchors. Calculating...")

except Exception as e:

print(f"❌ PARSE ERROR: {e}")

# Main Loop

client = mqtt.Client()

client.on_connect = on_connect

client.on_message = on_message

try:

client.connect(MQTT_BROKER_IP, MQTT_BROKER_PORT, 60)

client.loop_forever()

except Exception as e:

print(f"CONNECTION FAILED: {e}")

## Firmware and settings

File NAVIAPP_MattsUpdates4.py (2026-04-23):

#!/usr/bin/env python3
"""
NAVIAPP_movementtest_merged.py
================================
ARCHITECTURE  : old2.py  (state machine, heartbeat, telemetry buffer,
                           UWB confidence scorer, pairing manager,
                        enhanced GUI)
FOLLOW LOGIC  : movementtest.py  (LocalUwbTracker with is_pose_good(),
                                   UWB-lost safety stop in AUTO mode)
SPEED TUNING  : movementtest.py  (SPEED_CAP=20, TURN_CAP=20)
AVOIDANCE     : movementtest.py  (AV_REV=-15, AV_PIVOT=20)
LOAD CELL     : read_weight.py   (HX711 on DT=GPIO5 / SCK=GPIO6,
                                   auto-calibration on first boot saves to
                                   /home/pi/loadcell_calibration.json,
                                   weight displayed in lb + kg,
                                   luggage_fallen if weight < threshold,
                                   threshold + override pushed from app)
"""
import queue
import os
import json
import glob
import argparse
import logging
import serial
import time
import curses
import sys
import threading
import statistics
import uuid
from collections import deque
from datetime import datetime, timezone
from enum import Enum, auto
import csv
import math
from dataclasses import dataclass, field
from typing import Optional, Tuple

import lgpio as GPIO
from supabase import create_client, Client

try:
    try:
        import RPi.GPIO as RPIGPIO
    except RuntimeError:
        import rpi_lgpio as RPIGPIO
    from hx711 import HX711
    HX711_AVAILABLE = True
except ImportError as e:
    print(f"[LOADCELL] HX711 not available: {e}", file=sys.stderr)
    HX711_AVAILABLE = False


logging.basicConfig(
    filename='/tmp/rover_debug.log', # <--- Route all logs to the background file
    level=logging.WARNING,           # <--- Silence the 'INFO' HTTP spam!
    format="%(asctime)s [%(levelname)s] %(message)s",
    datefmt="%H:%M:%S",
)
log = logging.getLogger("uwb_host")
# ======================================================================================
# Validation CLI args  — parsed once at module level so all classes can read them
# ======================================================================================
def _parse_args():
    p = argparse.ArgumentParser(
        description="NAVI Rover Controller with Validation Logging",
        formatter_class=argparse.ArgumentDefaultsHelpFormatter,
    )
    p.add_argument("--test-name", default="UNSPECIFIED_TEST",
                   help="Short identifier logged in every CSV row, e.g. 'distance_step_response'")
    p.add_argument("--session-id", default=None,
                   help="Session UUID. Auto-generated if omitted.")
    p.add_argument("--log-dir", default="/home/pi5-1/Desktop/Luggage/validation_logs",
                   help="Directory for all validation CSV outputs")
    return p.parse_args()

_ARGS = _parse_args()

VALIDATION_LOG_DIR  = _ARGS.log_dir
CURRENT_TEST_NAME   = _ARGS.test_name
CURRENT_SESSION_ID  = _ARGS.session_id or str(uuid.uuid4())[:8]

# ---------- per-session sub-directory so runs never overwrite each other ----------
_SESSION_DIR = os.path.join(
    VALIDATION_LOG_DIR,
    f"{datetime.now().strftime('%Y%m%d_%H%M%S')}_{CURRENT_TEST_NAME}_{CURRENT_SESSION_ID}"
)
os.makedirs(_SESSION_DIR, exist_ok=True)

# Canonical CSV paths (all land inside the session folder)
ROVER_CSV_PATH    = os.path.join(_SESSION_DIR, "rover_telemetry.csv")
ROVER_EVENT_PATH  = os.path.join(_SESSION_DIR, "rover_events.csv")
ROVER_LATENCY_PATH= os.path.join(_SESSION_DIR, "rover_latency.csv")

print(f"[VALIDATION] Session dir : {_SESSION_DIR}", file=sys.stderr)
print(f"[VALIDATION] Test name   : {CURRENT_TEST_NAME}", file=sys.stderr)
print(f"[VALIDATION] Session ID  : {CURRENT_SESSION_ID}", file=sys.stderr)

UWB_CSV_PATH   = os.path.join(_SESSION_DIR, "uwb_positions.csv")
UWB_EVENT_PATH = os.path.join(_SESSION_DIR, "uwb_events.csv")


BAUD = 115200
DETECT_TIMEOUT_S = 12
PUBLISH_INTERVAL_S = 0.1

# Height compensation: project 3D slant range to floor-plane horizontal distance
# Set both to 0.0 to disable correction.
ANCHOR_HEIGHT_M = 0.27
TAG_HEIGHT_M = 1.13

# ── D_mid reference point offset ──────────────────────────────────────────────
# By default distance_m is measured from (0,0) — the midpoint between anchors.
# Set these to shift the reference point to somewhere else on the rover.
# e.g. REF_OFFSET_Y = 0.3 means 0.3 m in front of the anchor midpoint.
REF_OFFSET_X = 0.0   # metres, positive = towards anchor 2
REF_OFFSET_Y = 0.12  # metres, positive = in front of wall
MIN_VALID_CONTROL_M = 0.50       # ignore control distances below ~1.64 ft
MAX_CONTROL_DROP_M = 0.35        # ignore sudden drops > ~1.15 ft


AVOID_BUBBLE_MIN_CM = 45.0    # Tight carving for crawling speeds
AVOID_BUBBLE_MAX_CM = 85.0   # Long-range scanning for high speeds

AVOID_BRAKE_MIN_CM  = 30.0    # Late braking for crawling
AVOID_BRAKE_MAX_CM  = 150.0    # Early braking for sprinting

AVOID_MAX_FORCE_CM     = 25.0    # Distance where repulsion hits 100% power
AVOID_CENTER_FORCE     = 0.0     # Gentle push force from Center-Left/Right sensors
AVOID_FENDER_FORCE     = 50.0    # Hard carve force from Left/Right Fender sensors
AVOID_ESCAPE_FORCE     = 35.0    # Base spin force if trapped dead-center
AVOID_BOOST_MULTIPLIER = 1.0     # Multiplier to punch out of dead-center traps


# ======================================================================================
# State Machine Definition  [from old2.py]
# ======================================================================================
class RoverState(Enum):
    WAITING_FOR_PAIR  = auto()
    IDLE              = auto()
    AUTO              = auto()
    MANUAL            = auto()
    MANUAL_OVERRIDE   = auto()   # Manual with ultrasonic hard-stop only
    OBSTACLE_AVOID    = auto()
    HARD_STOP         = auto()
    LOST_UWB          = auto()
    EMERGENCY_STOP    = auto()


# ======================================================================================
# Load Cell Reader  [from read_weight.py — HX711 on DT=GPIO5 / SCK=GPIO6]
# ======================================================================================
# Default threshold: rover stops if weight drops BELOW this value.
# Overridable at runtime via rover_commands.luggage_weight_threshold_kg
LUGGAGE_WEIGHT_THRESHOLD_KG_DEFAULT = 1.0   # ~2.2 lb — tune to empty-tray weight
LOAD_CELL_REFERENCE_UNIT = 87               # fallback only — auto-calibration overrides this
LOAD_CELL_CALIBRATION_FILE = "/home/pi5-1/Desktop/Luggage/loadcell_calibration.json"
LOAD_CELL_DT_PIN   = 17                      # GPIO5  (BCM)
LOAD_CELL_SCK_PIN  = 27                      # GPIO6  (BCM)
LOAD_CELL_SAMPLES  = 5                      # readings averaged per measurement
LOAD_CELL_POLL_S   = 0.25                   # how often to read (seconds)
DEFAULT_FOLLOW_DISTANCE_CM = 100.0

# Piezo buzzer (weight-loss alarm)
BUZZER_GPIO_PIN = 24   # BCM 24 / physical pin 18
BUZZER_TONE_HZ  = 2200
BUZZER_ARM_MARGIN_KG = 0.0

# Weight unit helpers
def kg_to_lb(kg: float) -> float:
    return kg * 2.20462

def lb_to_kg(lb: float) -> float:
    return lb / 2.20462

def grams_to_lb(g: float) -> float:
    return g * 0.00220462

def fmt_weight(kg: float) -> str:
    """Returns weight as both lb and kg string for display."""
    return f"{kg_to_lb(kg):.2f} lb  ({kg:.3f} kg)"


def load_or_calibrate(hx) -> float:
    """
    Load saved reference unit from calibration file.
    If no file exists, use the fixed reference unit from read_weight.py behavior.
    Do NOT block startup waiting for known-weight calibration.
    """
    if os.path.exists(LOAD_CELL_CALIBRATION_FILE):
        try:
            with open(LOAD_CELL_CALIBRATION_FILE, "r") as f:
                data = json.load(f)
            ref = float(data["reference_unit"])
            cal_date = data.get("calibrated_at", "unknown date")
            print(f"[LOADCELL] Loaded calibration from {LOAD_CELL_CALIBRATION_FILE}", file=sys.stderr)
            print(f"[LOADCELL]   reference_unit={ref:.4f} calibrated={cal_date}", file=sys.stderr)
            return ref
        except Exception as e:
            print(f"[LOADCELL] Failed to load calibration file: {e}", file=sys.stderr)

    print(f"[LOADCELL] No calibration file found — using fixed reference_unit={LOAD_CELL_REFERENCE_UNIT}", file=sys.stderr)
    return float(LOAD_CELL_REFERENCE_UNIT)


class LoadCellReader:
    """
    Background thread that reads the HX711 load cell every LOAD_CELL_POLL_S seconds.
    Exposes:
      weight_kg         — latest smoothed weight (kg)
      luggage_fallen    — True when weight < threshold AND override is OFF
      tare_done         — True once tare has completed on startup
    """

    def __init__(self,
                 threshold_kg: float = LUGGAGE_WEIGHT_THRESHOLD_KG_DEFAULT,
                 weight_alarm_override: bool = False):
        self._lock             = threading.Lock()
        self._stop             = threading.Event()
        self._thread           = None
        self._hx               = None
        self._recent_weights = deque(maxlen=5)
        self._below_threshold_count = 0
        self._last_good_kg = 0.0
        self._hx_lock = threading.Lock()
        self._tare_in_progress = False

        # Public state (read from main loop)
        self.weight_kg         = 0.0
        self.luggage_fallen    = False
        self.tare_done         = False
        self.hw_available      = False
        self.last_error        = None

        # Tunables — updated from rover_commands / app
        self.threshold_kg      = float(threshold_kg)
        self.weight_alarm_override = bool(weight_alarm_override)

    def set_threshold(self, kg: float):
        with self._lock:
            self.threshold_kg = float(kg)

    def set_override(self, enabled: bool):
        with self._lock:
            self.weight_alarm_override = bool(enabled)

    
    def request_tare(self):
        def _do_tare():
            with self._lock:
                hx = self._hx
                hw_available = self.hw_available
                current_weight = self.weight_kg
                if self._tare_in_progress:
                    print("[LOADCELL] tare skipped: already in progress", file=sys.stderr)
                    return
                self._tare_in_progress = True

            try:
                if not hw_available or hx is None:
                    with self._lock:
                        self.last_error = "tare requested but HX711 is not available"
                    print("[LOADCELL] tare skipped: HX711 not available", file=sys.stderr)
                    return

                if current_weight > 0.2:
                    with self._lock:
                        self.last_error = (
                            f"tare blocked: current weight {current_weight:.3f} kg indicates tray is not empty"
                        )
                    print(f"[LOADCELL] tare blocked: tray not empty ({current_weight:.3f} kg)", file=sys.stderr)
                    return

                print("[LOADCELL] Re-taring with empty tray...", file=sys.stderr)
                with self._hx_lock:
                    hx.reset()
                    time.sleep(0.2)
                    hx.tare(times=20)

                with self._lock:
                    self.tare_done = True
                    self._recent_weights.clear()
                    self._below_threshold_count = 0
                    self.weight_kg = 0.0
                    self.last_error = None

                print("[LOADCELL] Re-tare complete.", file=sys.stderr)

            except Exception as e:
                with self._lock:
                    self.last_error = str(e)
                print(f"[LOADCELL] tare failed: {e}", file=sys.stderr)

            finally:
                with self._lock:
                    self._tare_in_progress = False

        threading.Thread(target=_do_tare, daemon=True).start()

    def start(self):
        if not HX711_AVAILABLE:
            print("[LOADCELL] hx711/RPi.GPIO not installed — load cell disabled", file=sys.stderr)
            with self._lock:
                self.hw_available = False
                self.luggage_fallen = True   # fail safe
                self.last_error = "HX711 library not available"
            return

        try:
            RPIGPIO.setwarnings(False)

            self._hx = HX711(LOAD_CELL_DT_PIN, LOAD_CELL_SCK_PIN)
            self._hx.set_reading_format("MSB", "MSB")
            self._hx.set_reference_unit(load_or_calibrate(self._hx))

            # Match standalone behavior
            self._hx.reset()

            print("[LOADCELL] Taring with empty tray (2s settle)…", file=sys.stderr)
            time.sleep(2)
            self._hx.tare(times=20)

            with self._lock:
                self.tare_done = True
                self.hw_available = True
                self.last_error = None

            print("[LOADCELL] Tare done. Reading started.", file=sys.stderr)

            self._thread = threading.Thread(target=self._run, daemon=True)
            self._thread.start()

        except Exception as e:
            print(f"[LOADCELL] start() failed: {e}", file=sys.stderr)
            with self._lock:
                self.hw_available = False
                self.luggage_fallen = True   # fail safe
                self.last_error = str(e)

    def stop(self):
        self._stop.set()
        if self._thread:
            self._thread.join(timeout=2.0)
        if self._hx is not None:
            try:
                self._hx.power_down()
            except:
                pass
        try:
            RPIGPIO.cleanup()
        except:
            pass

    def get(self) -> dict:
        """Return a snapshot of current load-cell state (thread-safe)."""
        with self._lock:
            return {
                "weight_kg":         self.weight_kg,
                "luggage_fallen":    self.luggage_fallen,
                "tare_done":         self.tare_done,
                "hw_available":      self.hw_available,
                "threshold_kg":      self.threshold_kg,
                "override":          self.weight_alarm_override,
                "last_error":        self.last_error,
            }

    def _run(self):
        while not self._stop.is_set():
            try:
                with self._lock:
                    tare_in_progress = self._tare_in_progress

                if tare_in_progress:
                    time.sleep(0.1)
                    continue

                with self._hx_lock:
                    grams = self._hx.get_weight(5)
                    print(f"[LOADCELL_RAW] grams={grams}", file=sys.stderr)

                    kg = max(0.0, grams / 1000.0)

                    self._hx.power_down()
                    self._hx.power_up()

                with self._lock:
                    self.weight_kg = kg
                    if not self.weight_alarm_override:
                        self.luggage_fallen = (kg < self.threshold_kg)
                    else:
                        self.luggage_fallen = False
                    self.last_error = None

                print(f"[LOADCELL_OK] kg={kg:.3f}", file=sys.stderr)

            except Exception as e:
                with self._lock:
                    self.last_error = str(e)
                print(f"[LOADCELL] read error: {e}", file=sys.stderr)

            time.sleep(0.2)
    # def _run(self):
    #     while not self._stop.is_set():
    #         try:
    #             grams = self._hx.get_weight(LOAD_CELL_SAMPLES)
    #             print(f"[LOADCELL_RAW] grams={grams}", file=sys.stderr)
    #             self._hx.power_down()
    #             time.sleep(0.05)
    #             self._hx.power_up()
    #             time.sleep(0.05)

    #             kg_raw = grams / 1000.0
    #             print(f"[LOADCELL_OK] kg_raw={kg_raw:.3f} kg={kg:.3f}", file=sys.stderr)

    #             # clamp small negatives to zero
    #             if kg_raw < 0:
    #                 kg_raw = 0.0

    #             # reject impossible spikes
    #             # tune 60.0 to your actual max luggage weight
    #             if kg_raw > 60.0:
    #                 raise ValueError(f"Rejected unrealistic load cell value: {kg_raw:.3f} kg")

    #             # reject sudden one-sample jumps
    #             if self._recent_weights and abs(kg_raw - self._recent_weights[-1]) > 15.0:
    #                 raise ValueError(f"Rejected sudden jump: {self._recent_weights[-1]:.3f} -> {kg_raw:.3f} kg")

    #             self._recent_weights.append(kg_raw)
    #             kg = statistics.median(self._recent_weights)
    #             self._last_good_kg = kg

    #             with self._lock:
    #                 self.weight_kg = kg

    #                 if not self.weight_alarm_override:
    #                     if kg < self.threshold_kg:
    #                         self._below_threshold_count += 1
    #                     else:
    #                         self._below_threshold_count = 0

    #                     # require 3 consecutive low reads
    #                     self.luggage_fallen = self._below_threshold_count >= 3
    #                 else:
    #                     self._below_threshold_count = 0
    #                     self.luggage_fallen = False

    #                 self.last_error = None

    #         except Exception as e:
    #             with self._lock:
    #                 self.last_error = str(e)
    #                 # keep last known weight, do not force a bogus new value
    #             print(f"[LOADCELL] read error: {e}", file=sys.stderr)

    #         time.sleep(LOAD_CELL_POLL_S)


class PiezoAlarm:
    """
    Continuous Siren Alarm (Latched & Active-Low)
    """

    def __init__(self, gpio_pin: int = BUZZER_GPIO_PIN, tone_hz: float = BUZZER_TONE_HZ):
        self.gpio_pin = int(gpio_pin)
        self._chip = None
        self._lock = threading.Lock()

        # State tracking
        self._armed = False
        self._alarm_latched = False
        self.hw_available = False

        # Hardware logic: Active-Low
        self.SILENT = 1  # HIGH keeps it quiet
        self.SIREN = 0  # LOW sounds the alarm

        self._pin_state = None

    def start(self):
        try:
            self._chip = GPIO.gpiochip_open(0)
            GPIO.gpio_claim_output(self._chip, self.gpio_pin)
            self._write(self.SILENT)  # Default to silent on startup
            self.hw_available = True
        except Exception as e:
            self.hw_available = False
            print(f"[BUZZER] start() failed: {e}", file=sys.stderr)

    def stop(self):
        try:
            if self._chip is not None:
                # Float the pin so your physical pull-up resistor can take over
                GPIO.gpio_free(self._chip, self.gpio_pin)
                GPIO.gpio_claim_input(self._chip, self.gpio_pin)
                GPIO.gpiochip_close(self._chip)
        except Exception as e:
            print(f"[BUZZER] Shutdown error: {e}", file=sys.stderr)

        self._chip = None
        self._pin_state = self.SILENT

    def update(self, weight_kg: float, threshold_kg: float, hw_available: bool, override: bool, state_name: str,
               uwb_age_s: float):
        with self._lock:
            # 1. Hardware unavailable
            if not self.hw_available or not hw_available:
                self._write(self.SILENT)
                return

            # 2. Priority 1: Luggage Alarm (Continuous Siren)
            # Still safely locked behind the override switch!
            if not bool(override) and state_name in ["AUTO", "HARD_STOP"]:
                if float(weight_kg) < float(threshold_kg):
                    self._write(self.SIREN)
                    return  # Exit early, continuous siren wins

            # 3. Priority 2: UWB Diagnostic Alarm (Beep Pattern)
            # THE FIX: Removed the override check here! This will now monitor
            # the UWB tracking data 24/7, regardless of the luggage switch.
            if uwb_age_s is not None and uwb_age_s > 3.0:
                cycle_time = time.time() % 2.0

                # Beep 1: 0.0s to 0.15s | Beep 2: 0.3s to 0.45s
                if (0.0 <= cycle_time < 0.15) or (0.3 <= cycle_time < 0.45):
                    self._write(self.SIREN)
                else:
                    self._write(self.SILENT)
                return

            # 4. Otherwise, stay silent
            self._write(self.SILENT)

    def _write(self, level: int):
        if self._chip is None:
            return
            
        if level != self._pin_state:
            try:
                # THE FIX: Clean, standard GPIO output now that you are on 3.3V power!
                GPIO.gpio_write(self._chip, self.gpio_pin, level)
                self._pin_state = level
            except Exception as e:
                print(f"[BUZZER] write failed: {e}", file=sys.stderr)


# ======================================================================================
# Telemetry Buffer  [from old2.py]
# ======================================================================================
class _CsvBase:
    """Shared CSV writer used by all logger classes below."""
    def __init__(self, path: str, fieldnames: list):
        self.path       = path
        self.fieldnames = fieldnames
        self._lock      = threading.Lock()
        os.makedirs(os.path.dirname(path), exist_ok=True)
        with open(path, "w", newline="") as f:   # always create fresh per session
            csv.DictWriter(f, fieldnames=fieldnames).writeheader()

    def write_row(self, row: dict):
        with self._lock:
            with open(self.path, "a", newline="") as f:
                csv.DictWriter(f, fieldnames=self.fieldnames).writerow(row)
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

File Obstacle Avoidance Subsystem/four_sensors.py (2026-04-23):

# 4x HC-SR04 on Raspberry Pi (lgpio)
# Adaptive-speed EMA streaming + 3-hit debounce + smart avoidance
# BCM/phys pin map kept the same as you wired:
# front: TRIG=23 (16), ECHO=12 (32)
# right: TRIG=25 (22), ECHO=16 (36)
# left : TRIG=8  (24), ECHO=20 (38)
# back : TRIG=7  (26), ECHO=21 (40)

import time, statistics
import lgpio as GPIO

SENSORS = {
    "front": {"trig": 23, "echo": 12},
    "right": {"trig": 25, "echo": 16},
    "left":  {"trig": 8,  "echo": 20},
    "back":  {"trig": 7,  "echo": 21},
}

# ---------------- Tunables (FAST profile) ----------------
THRESHOLD_CM     = 61
HYSTERESIS_CM    = 10            # re-arm when EMA > 71 cm
DEBOUNCE_HITS    = 3             # need 3 consecutive EMA <= threshold
EMA_ALPHA        = 0.42          # snappier EMA (0.25 smoother, 0.5 very quick)

NEAR_CM          = 120           # use "near" settings when EMA <= this
SAMPLES_NEAR     = 7             # raw pings if near
SAMPLES_FAR      = 3             # raw pings if far
PING_GAP_NEAR    = 0.010         # gap between raw pings (near)
PING_GAP_FAR     = 0.006         # gap between raw pings (far)
INTER_SENSOR_GAP = 0.003         # quiet time between sensors

# Echo timeouts (far vs near) — front/back a bit longer
ECHO_TO_FAR  = {"front": 0.12, "back": 0.12, "right": 0.08, "left": 0.08}
ECHO_TO_NEAR = {"front": 0.08, "back": 0.08, "right": 0.06, "left": 0.06}

SPEED_CM_S       = 34300
TRIG_PULSE_S     = 12e-6
MIN_CM, MAX_CM   = 2, 400
MISSES_TO_BLANK  = 3             # show "--" quickly if data disappears
POST_EVENT_PAUSE = 0.05          # settle echoes after avoidance
CLEAR_MARGIN     = 8             # extra cm to call a direction "clear"
# ---------------------------------------------------------

def motor_forward(): print("[MOTOR] FORWARD")
def motor_stop():    print("[MOTOR] STOP")
def motor_reverse(t=0.35):
    print(f"[MOTOR] REVERSE {t:.2f}s"); time.sleep(t); print("[MOTOR] REVERSE done")
def motor_pivot_left(t=0.35):
    print(f"[MOTOR] PIVOT LEFT {t:.2f}s"); time.sleep(t); print("[MOTOR] PIVOT done")
def motor_pivot_right(t=0.35):
    print(f"[MOTOR] PIVOT RIGHT {t:.2f}s"); time.sleep(t); print("[MOTOR] PIVOT done")

def wait_for(h, pin, level, timeout):
    end = time.perf_counter() + timeout
    while time.perf_counter() < end:
        if GPIO.gpio_read(h, pin) == level:
            return time.perf_counter()
    return None

def ping_once(h, trig, echo, to):
    GPIO.gpio_write(h, trig, 0); time.sleep(5e-6)
    GPIO.gpio_write(h, trig, 1); time.sleep(TRIG_PULSE_S)
    GPIO.gpio_write(h, trig, 0)
    t0 = wait_for(h, echo, 1, to)
    if t0 is None: return None
    t1 = wait_for(h, echo, 0, to)
    if t1 is None: return None
    d = (t1 - t0) * SPEED_CM_S / 2.0
    return d if (MIN_CM <= d <= MAX_CM) else None

def robust_measure_adaptive(h, name, trig, echo, ema_prev):
    """Adaptive sampler: fewer pings + shorter timeouts when far; more when near."""
    near = (ema_prev is not None) and (ema_prev <= NEAR_CM)
    n    = SAMPLES_NEAR if near else SAMPLES_FAR
    to   = ECHO_TO_NEAR.get(name, 0.08) if near else ECHO_TO_FAR.get(name, 0.08)
    gap  = PING_GAP_NEAR if near else PING_GAP_FAR

    vals = []
    for _ in range(n):
        d = ping_once(h, trig, echo, to)
        if d is not None:
            vals.append(d)
        time.sleep(gap)

    if not vals:
        return None

    med  = statistics.median(vals)
    devs = [abs(v - med) for v in vals]
    mad  = statistics.median(devs) if devs else 0
    keep = [v for v, dv in zip(vals, devs) if dv <= 2.5*mad] if mad > 0 else vals
    if not keep: keep = vals
    return statistics.median(keep)

def choose_avoid_action(trigger_name, ema):
    def d(n): v = ema.get(n); return v if v is not None else 0.0
    f, r, l, b = d("front"), d("right"), d("left"), d("back")
    clear_level = THRESHOLD_CM + CLEAR_MARGIN
    f_clear, r_clear, l_clear, b_clear = (f > clear_level, r > clear_level, l > clear_level, b > clear_level)
    print(f"[DECIDE] f={int(f)} r={int(r)} l={int(l)} b={int(b)} (clear > {int(clear_level)})")

    if trigger_name == "front":
        if b_clear: motor_stop(); motor_reverse(0.35); motor_forward(); return
        if r >= l and r > THRESHOLD_CM: motor_stop(); motor_pivot_right(0.35); motor_forward()
        elif l > r and l > THRESHOLD_CM: motor_stop(); motor_pivot_left(0.35); motor_forward()
        else: motor_stop(); motor_reverse(0.25); (motor_pivot_right(0.35) if r >= l else motor_pivot_left(0.35)); motor_forward()
    elif trigger_name == "back":
        if f_clear: motor_stop(); motor_forward(); return
        if r >= l and r > THRESHOLD_CM: motor_stop(); motor_pivot_right(0.35); motor_forward()
        elif l > r and l > THRESHOLD_CM: motor_stop(); motor_pivot_left(0.35); motor_forward()
        else: motor_stop(); motor_forward(); (motor_pivot_right(0.35) if r >= l else motor_pivot_left(0.35)); motor_forward()
    elif trigger_name == "left":
        if r_clear: motor_stop(); motor_pivot_right(0.25); motor_forward()
        elif f_clear: motor_stop(); motor_forward()
        elif b_clear: motor_stop(); motor_reverse(0.35); motor_forward()
        else: motor_stop(); motor_pivot_right(0.35); motor_forward()
    elif trigger_name == "right":
        if l_clear: motor_stop(); motor_pivot_left(0.25); motor_forward()
        elif f_clear: motor_stop(); motor_forward()
        elif b_clear: motor_stop(); motor_reverse(0.35); motor_forward()
        else: motor_stop(); motor_pivot_left(0.35); motor_forward()
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

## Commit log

2026-04-23 Add files via upload
    tests the ultrasonic sensors and displays distance data
2026-04-23 Rename App Subsystem/devices_page.dart to App Subsystem/lib/devices_page.dart
2026-04-23 Add files via upload
    Adding relevant files for 404
    [Buck Converter Holder.ipt, Luggage Mount.ipt, Wheel Arch Mirrored.ipt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]
